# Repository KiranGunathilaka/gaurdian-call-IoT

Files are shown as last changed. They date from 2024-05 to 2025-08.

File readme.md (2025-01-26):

# GuardianCall : Multipurposed elctronic pager IoT device

GuardianCall, is a electronic pager that is developed for the ease of caretakers and bed-ridden inidividuals. This device is intended for both single patient - single caretaker and many patients - many caretakers situations.

## Market pitch

Designed by [Venumi Gihansa Gunasekara](https://github.com/venumigihansa)
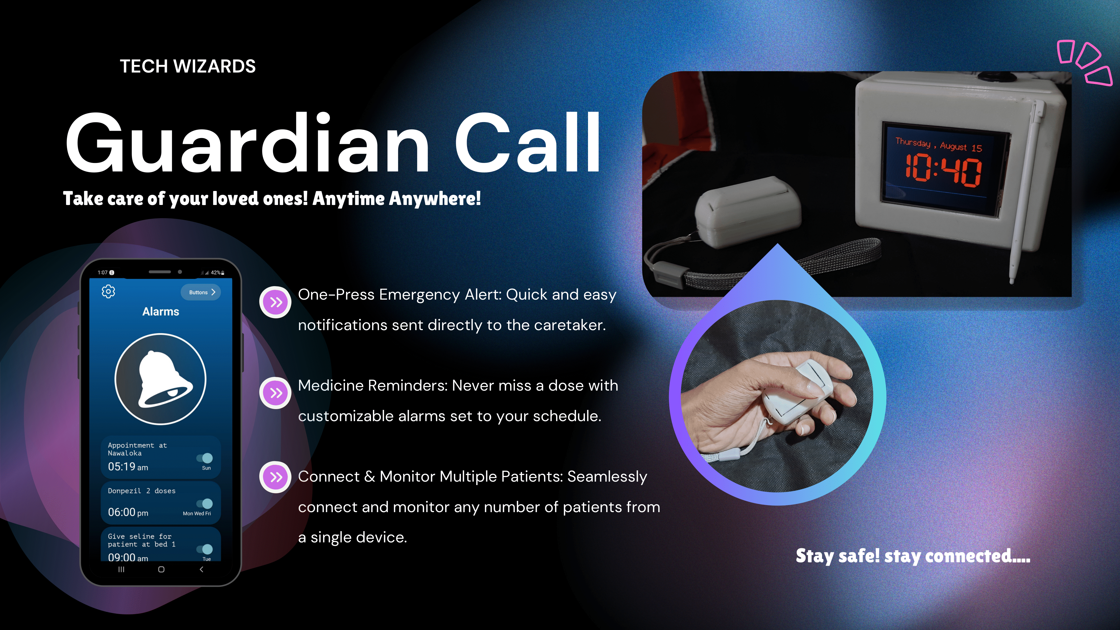
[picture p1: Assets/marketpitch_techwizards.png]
Market Pitch


## System Block Diagram

There was a major bug in the ESP32 libraries (even remaining unresolved for years in the forums), not operating WiFi and ESP Now at the same time even when the wifi channels are configured. There was no errors or execeptions throwed so we had to try different appoaches.
So after 3 system desgin iterations and considering their pros and cons we implemented our device using the following architecture.

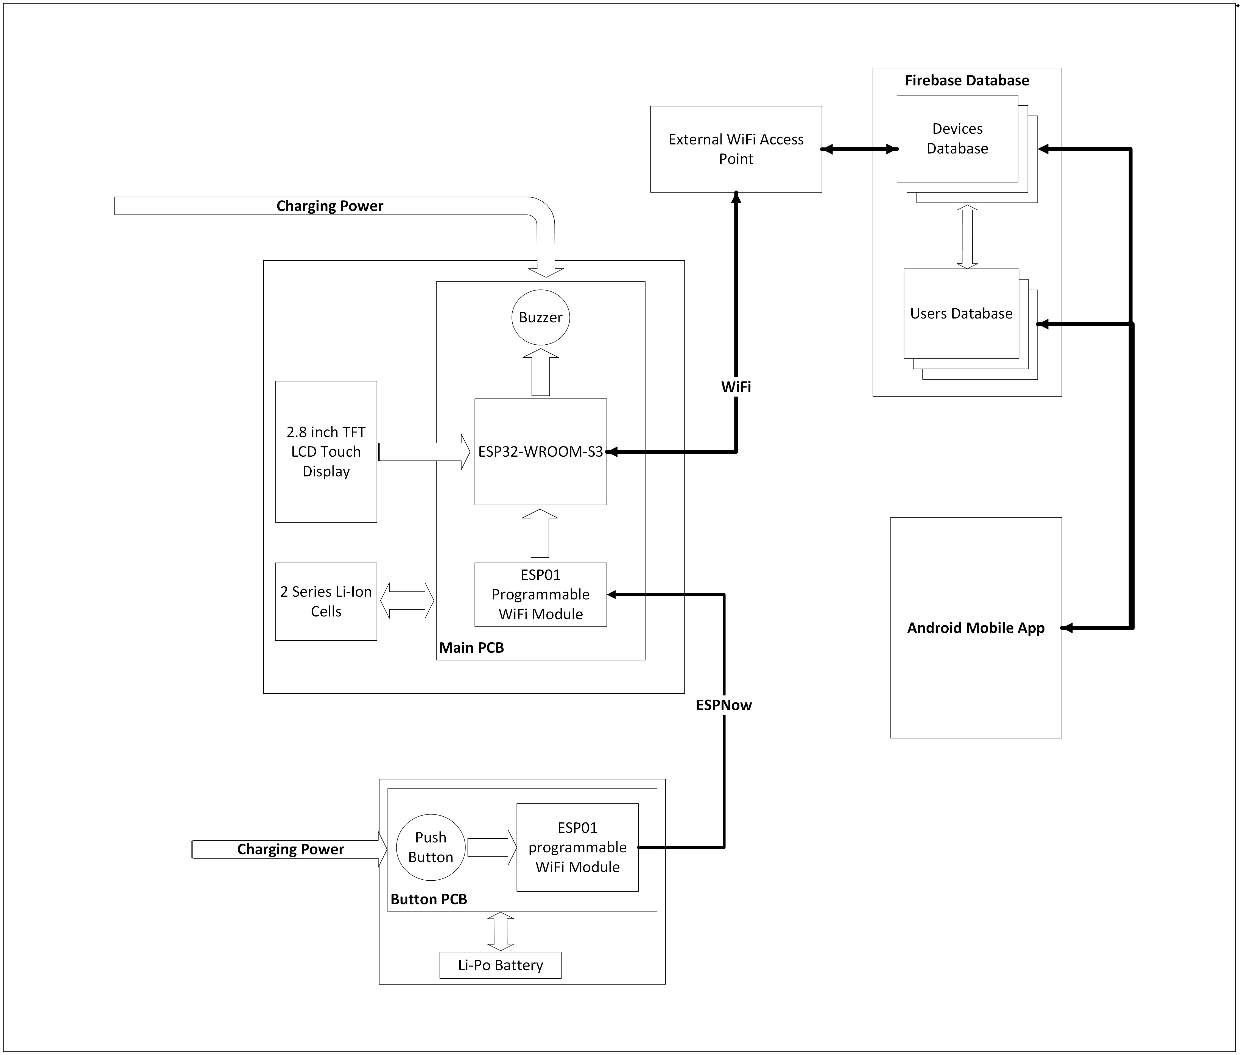
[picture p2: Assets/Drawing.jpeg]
Block diagram


## PCB Design

### Main Unit

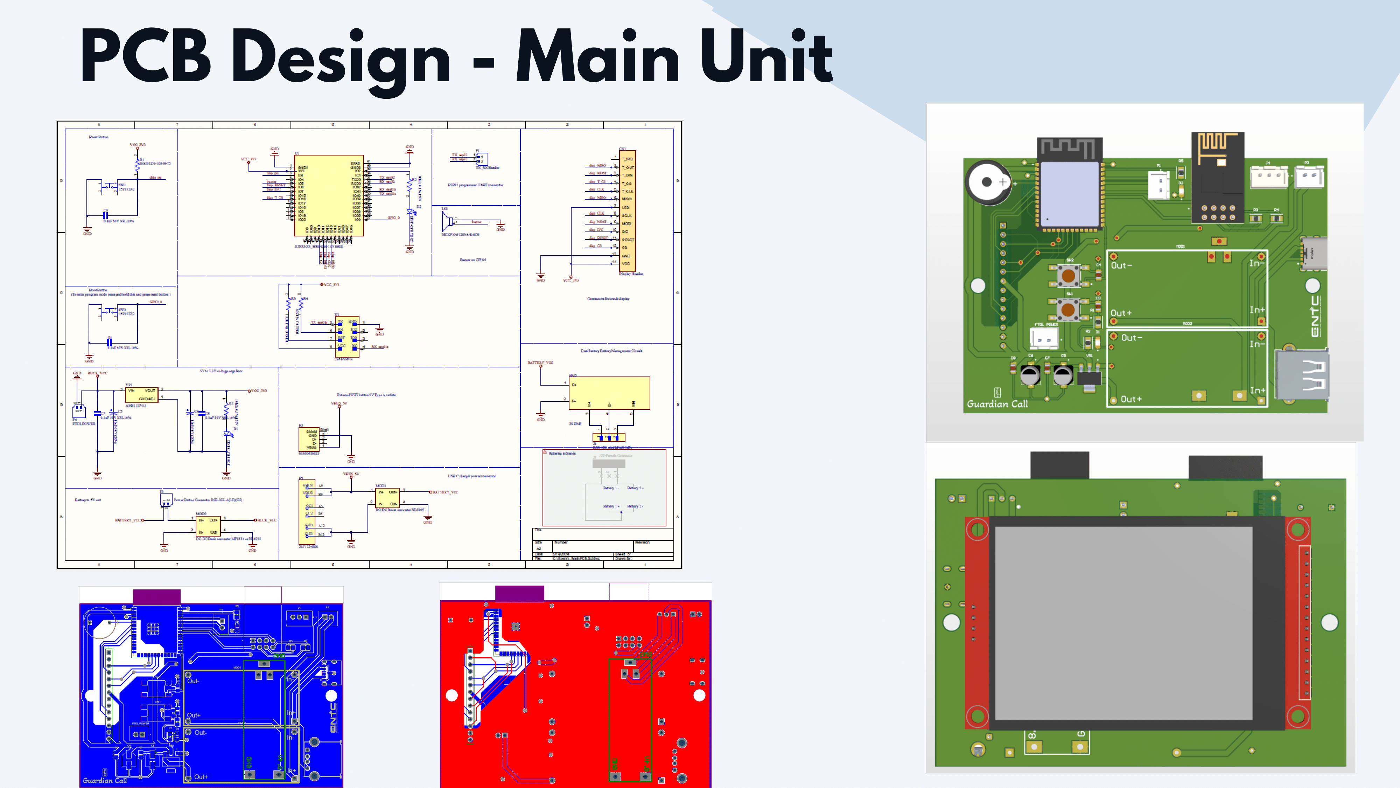
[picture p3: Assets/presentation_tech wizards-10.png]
Main PCB


### Button

Desgined by [Imansha Manuka Priyanjana](https://github.com/imansha321?tab=followers)
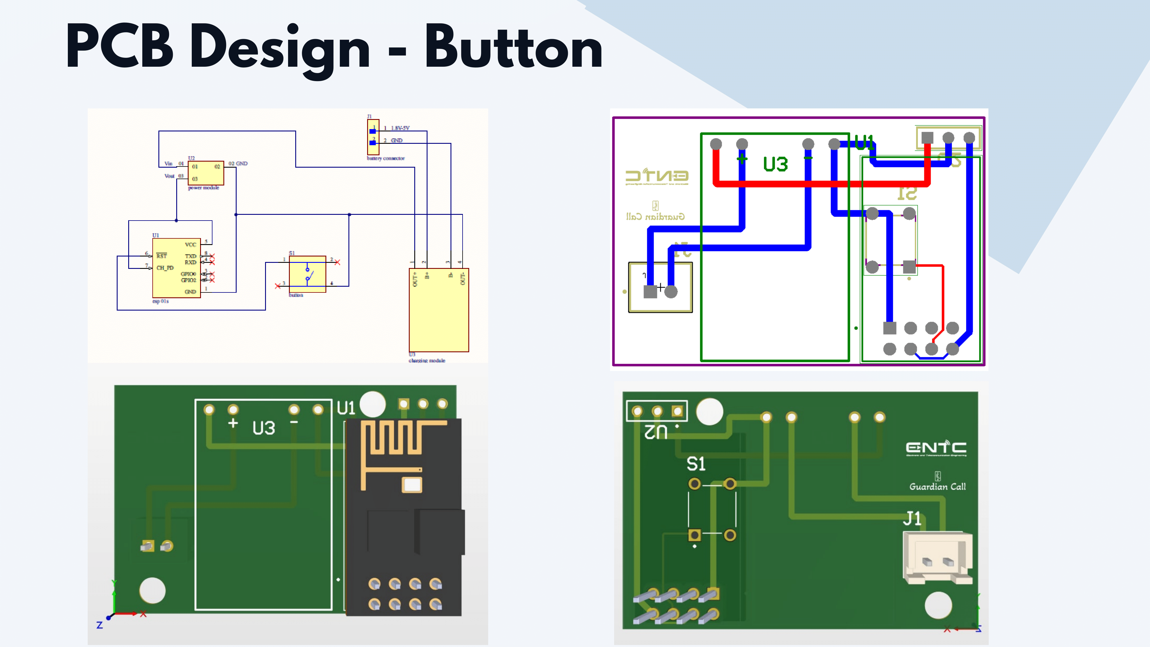
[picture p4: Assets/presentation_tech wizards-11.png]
Button PCB


<div style="display: flex; justify-content: space-around; text-align: center;">
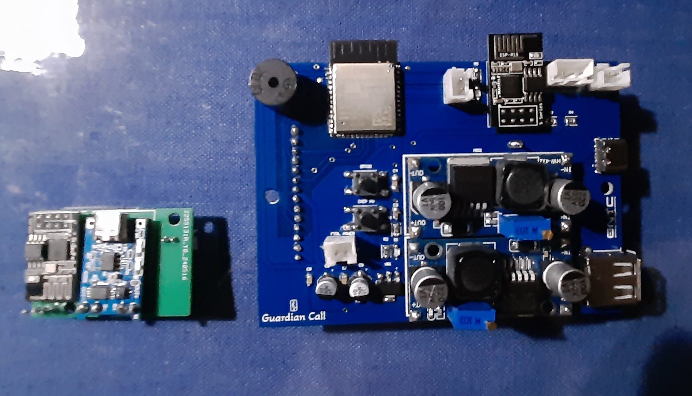
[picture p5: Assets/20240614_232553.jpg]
    
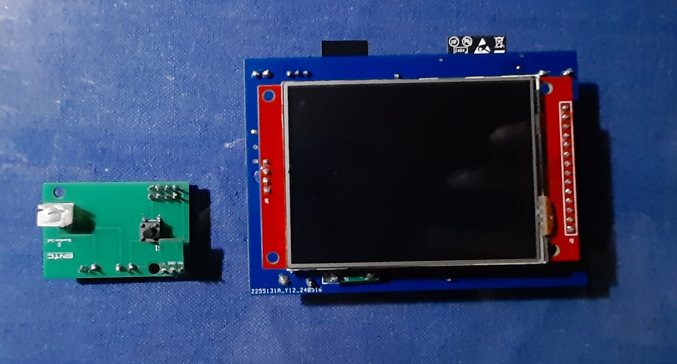
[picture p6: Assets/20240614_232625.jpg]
    
</div>

## Enclosure Design

Designed by [Induwara Illukumbura](https://github.com/induwara-iluk)
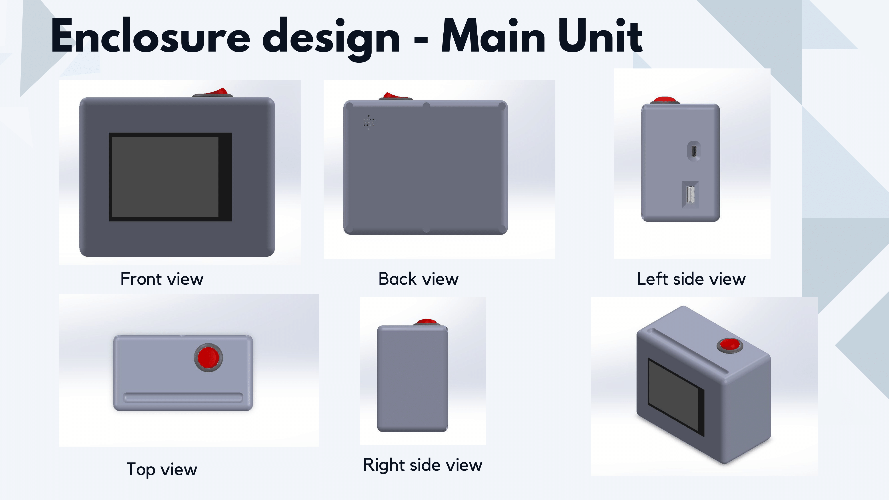
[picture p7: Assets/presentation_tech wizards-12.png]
Main unit enclosure

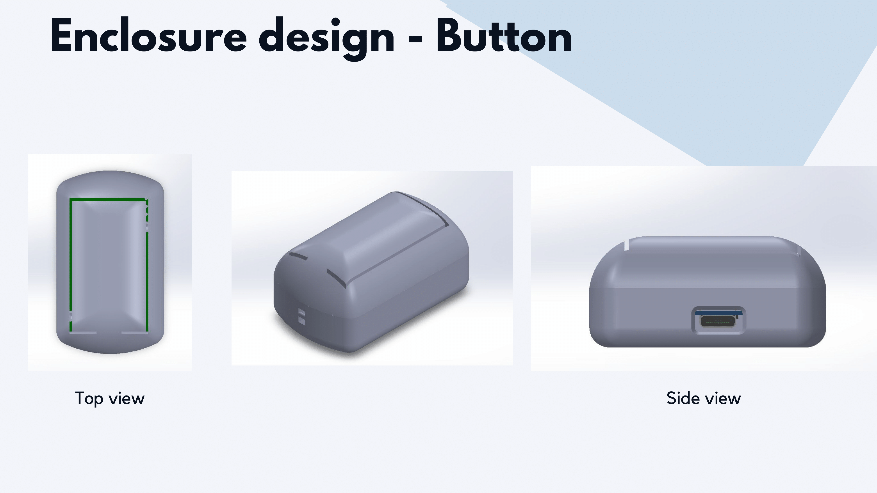
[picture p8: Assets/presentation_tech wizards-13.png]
Button enclosure


# UI of Guardian call
The existing UI is built with the TFT_eSPI library and furthur improvements will be made using LVGL.

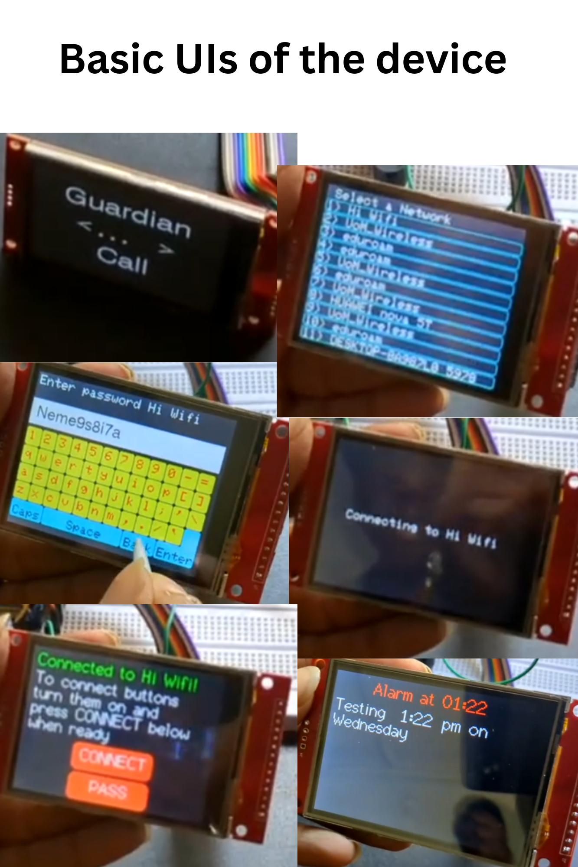
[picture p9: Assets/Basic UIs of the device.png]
UIs


## App overview

App was designed scalability and giving best user experience in mind. 

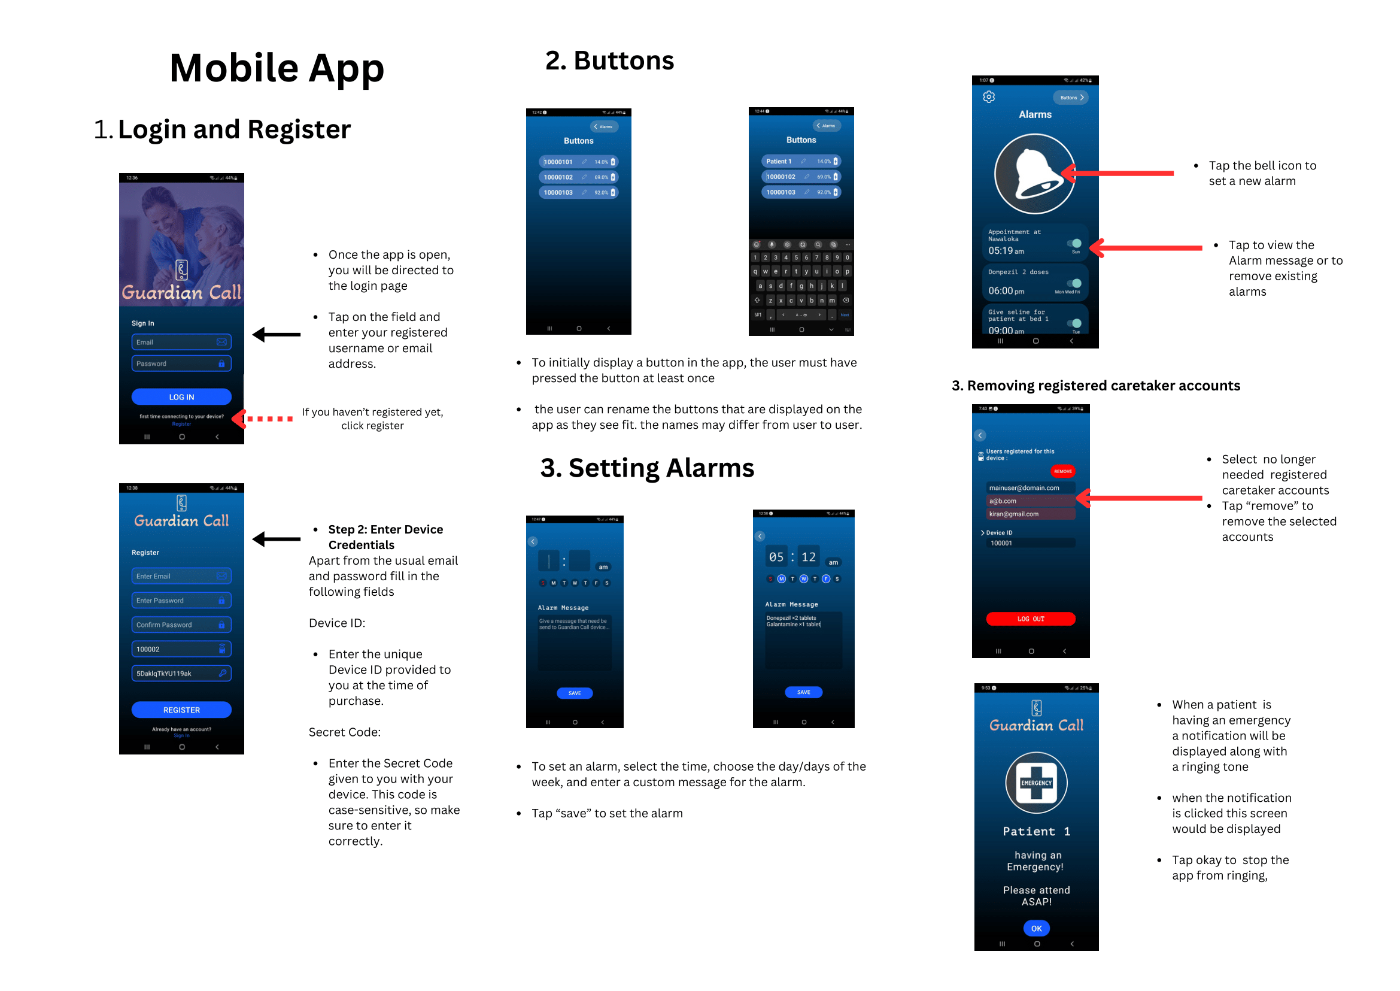
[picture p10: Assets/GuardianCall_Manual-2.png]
UI of the android app

Image credit [Venumi Gihansa Gunasekara](https://github.com/venumigihansa)

For the backend we used firebase and it's BaaS tools and the realtime database was also structured for scalabiluty making overall system architecture cabale of adding any number of new devices, users and any number of buttons for each device (but from the IoT device's firmware it is limite to 100)

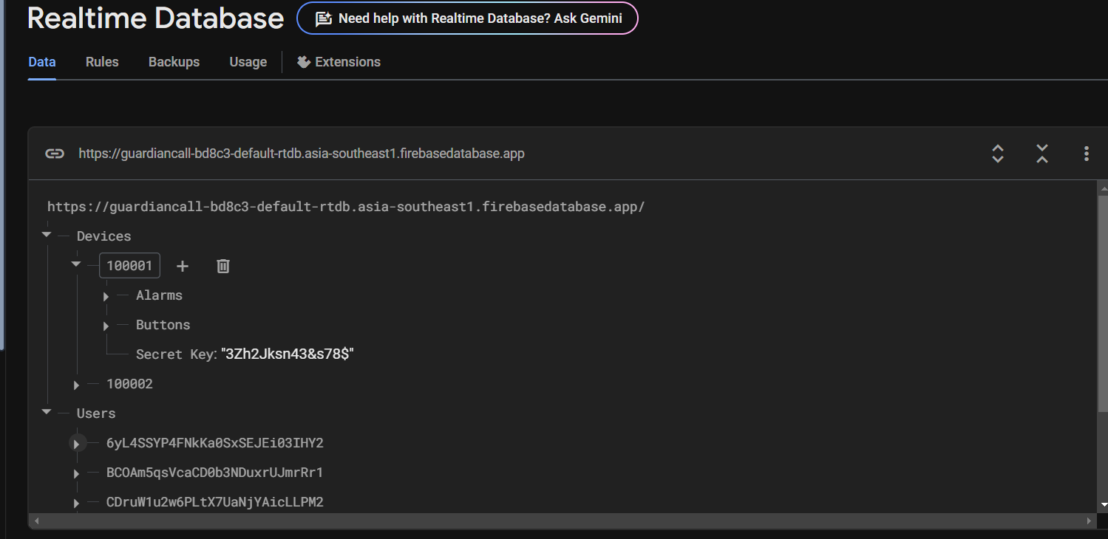
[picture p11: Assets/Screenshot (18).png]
Structure of the Realtime Database


Refer below for the source files and distributions

[Original Girhub Repo for the App](https://github.com/KiranGunathilaka/guardian-call-app)

To securely register a caretaker with a device, following sign-up cards are needed.

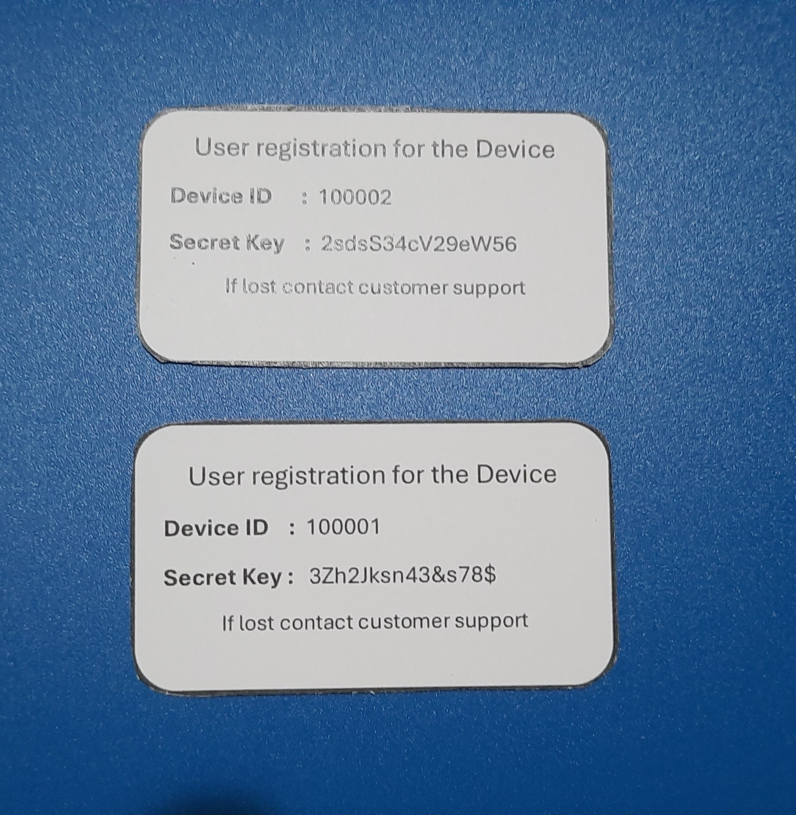
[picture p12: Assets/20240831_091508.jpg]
Sign-Up Card


## Actual Device

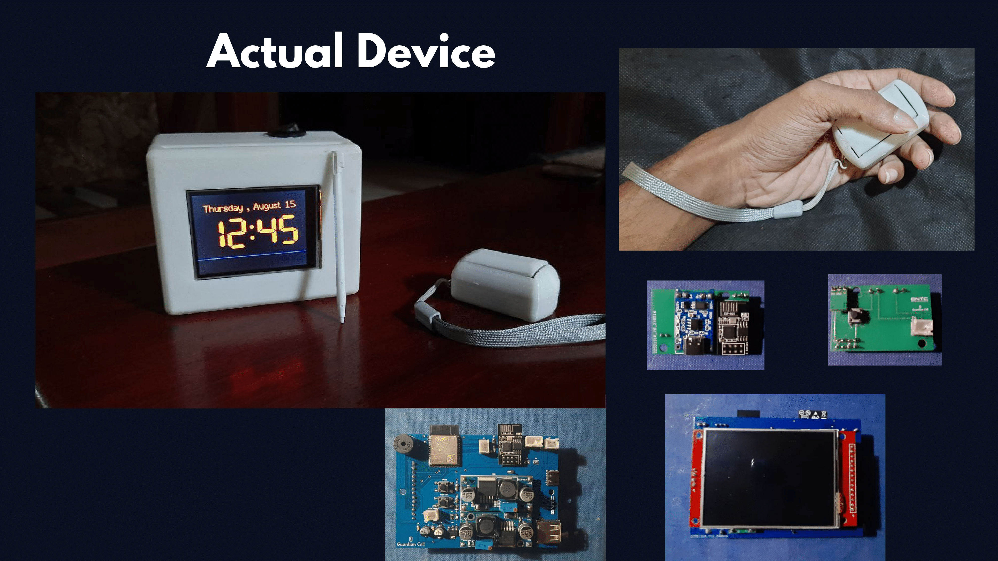
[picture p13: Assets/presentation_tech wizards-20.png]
Image of the device and pcbs


## Some videos in the prototyping phase

[Video 1, before the final circuit implmentation](Assets/VID-20240509-WA0002.mp4)

[Video 2, before using ESP01 for the button, for the proposal evalution](/Assets/VID-20240501-WA0005.mp4)

Furthur updates to the main unit is possible via a USB to TTL converter, so it is possible to make furthur improvements to the hardware after assembling.

For more information, refer to the project report, presentation pdfs above.

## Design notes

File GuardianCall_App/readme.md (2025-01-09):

# GuardianCall App

## Introduction 
Guardian call app is the mobile user interface for the GuardianCall electronic pager IoT device. Developed using android studio and java it is used for the caretakers/owners to login, register for the device, receive alert calls from the patients/Button wearers, Set alarms for the IoT device or/and app, receive alrams from the device and manage users.

## Design Overview

<div style="display: flex; justify-content: space-around; text-align: center;">
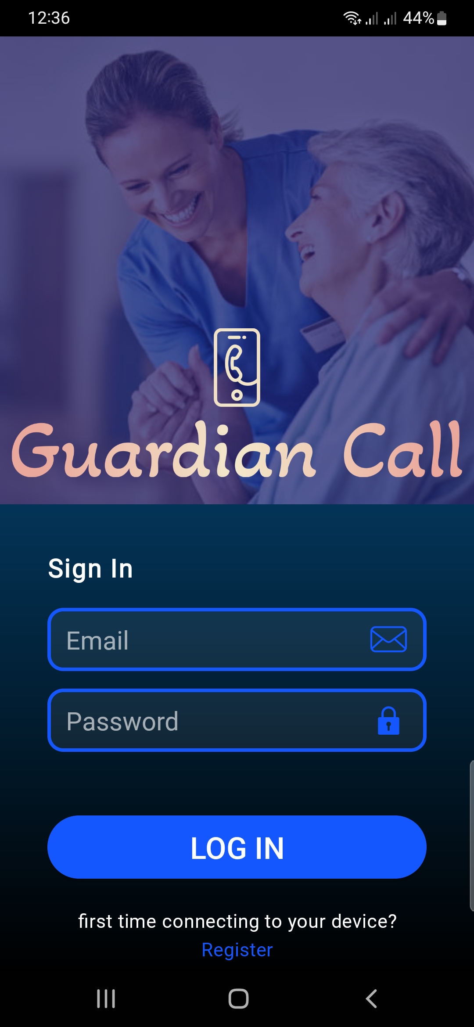
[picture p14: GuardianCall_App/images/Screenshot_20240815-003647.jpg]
  
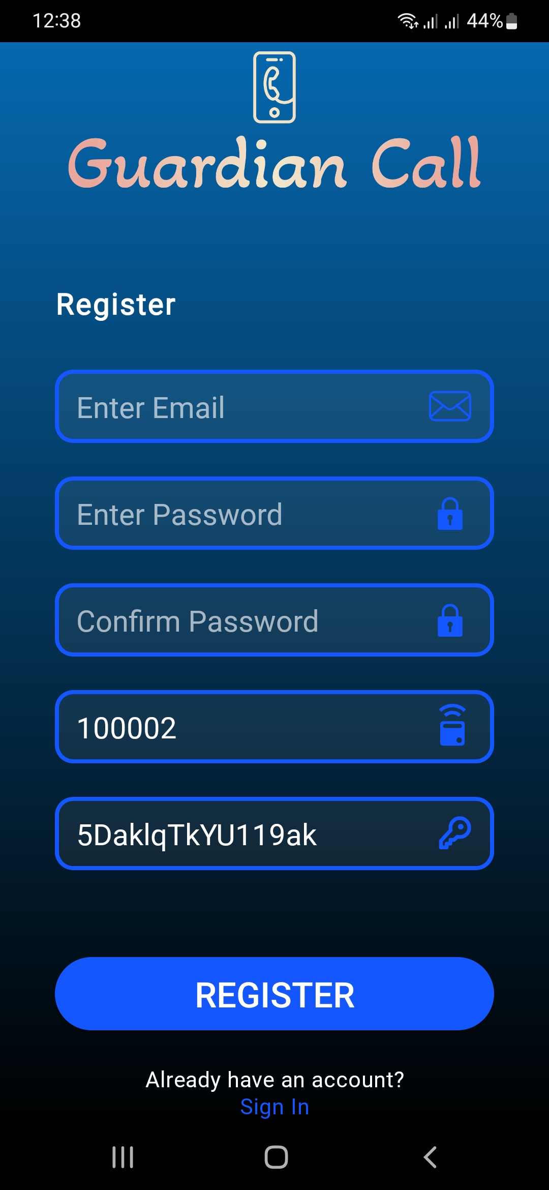
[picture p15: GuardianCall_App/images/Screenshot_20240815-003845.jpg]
  
</div>

<div style="display: flex; justify-content: space-around; text-align: center;">
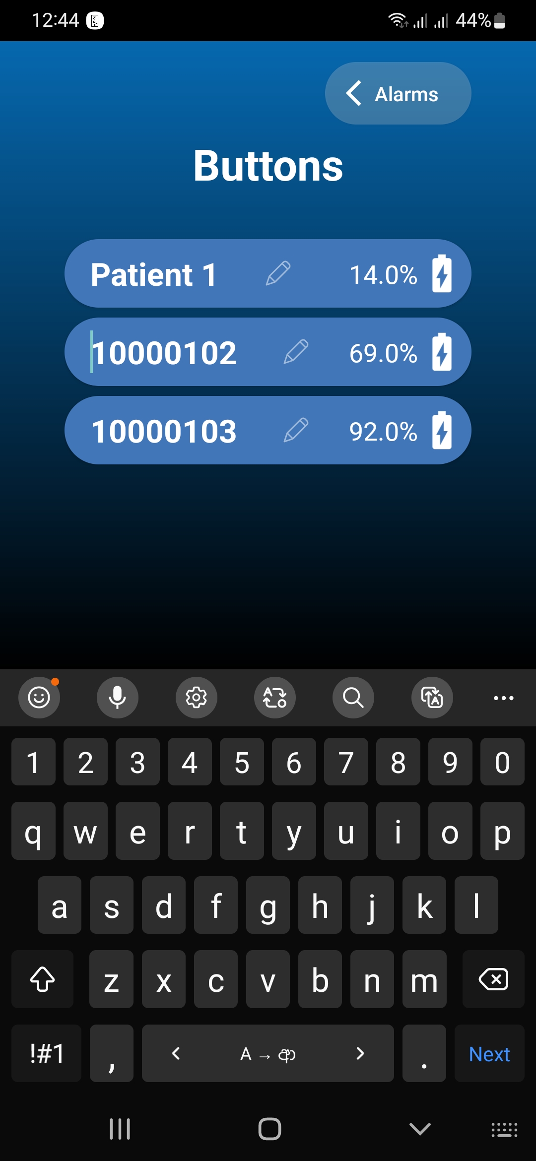
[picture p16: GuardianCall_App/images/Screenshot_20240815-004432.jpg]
    
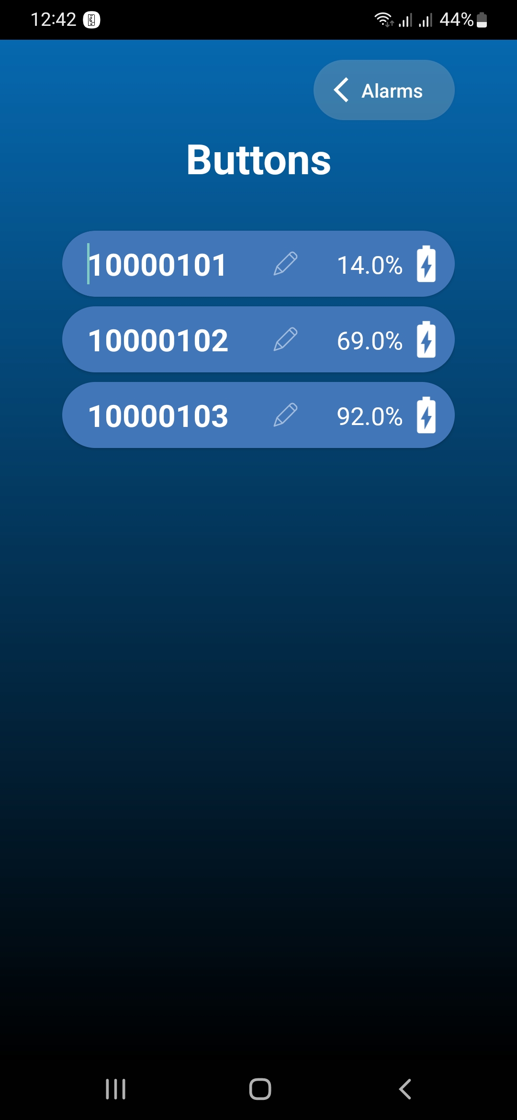
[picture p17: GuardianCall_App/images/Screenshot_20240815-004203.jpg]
    
</div>

<div style="display: flex; justify-content: space-around; text-align: center;">
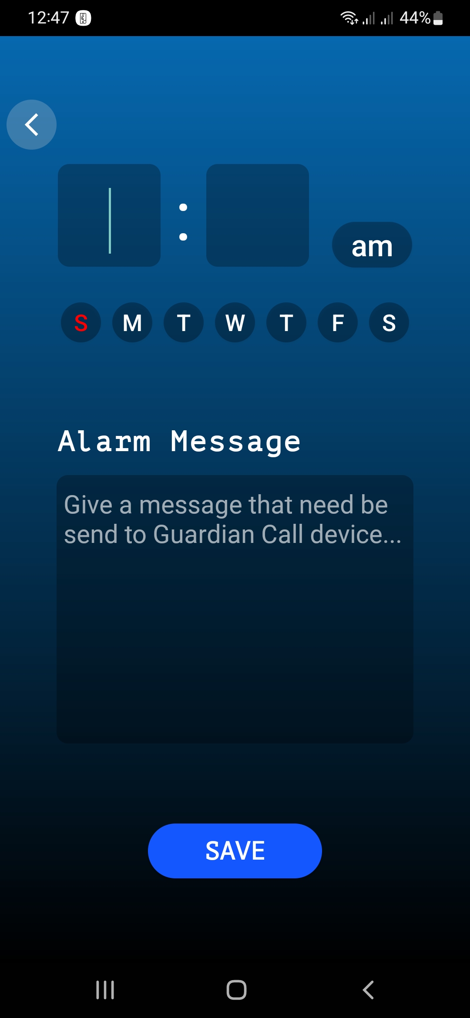
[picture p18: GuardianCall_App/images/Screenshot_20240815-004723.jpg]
    
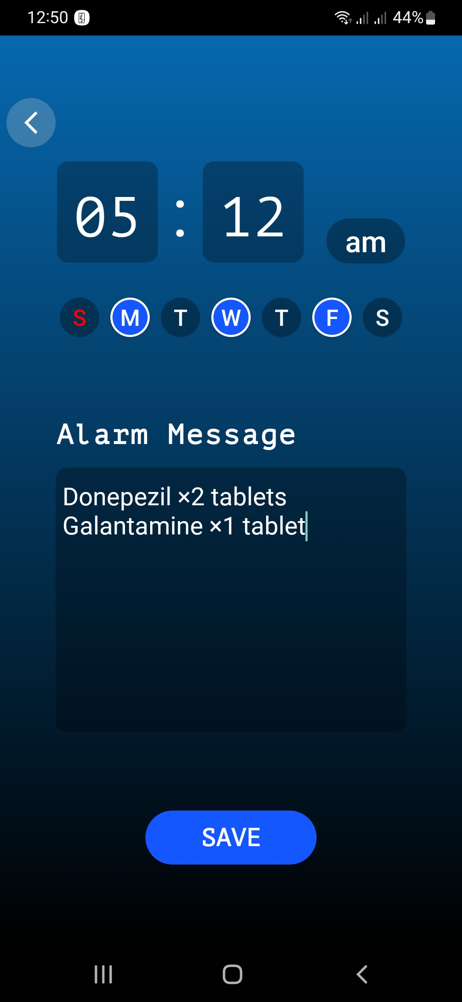
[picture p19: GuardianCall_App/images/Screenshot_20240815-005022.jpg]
    
</div>

<div style="display: flex; justify-content: space-around; text-align: center;">
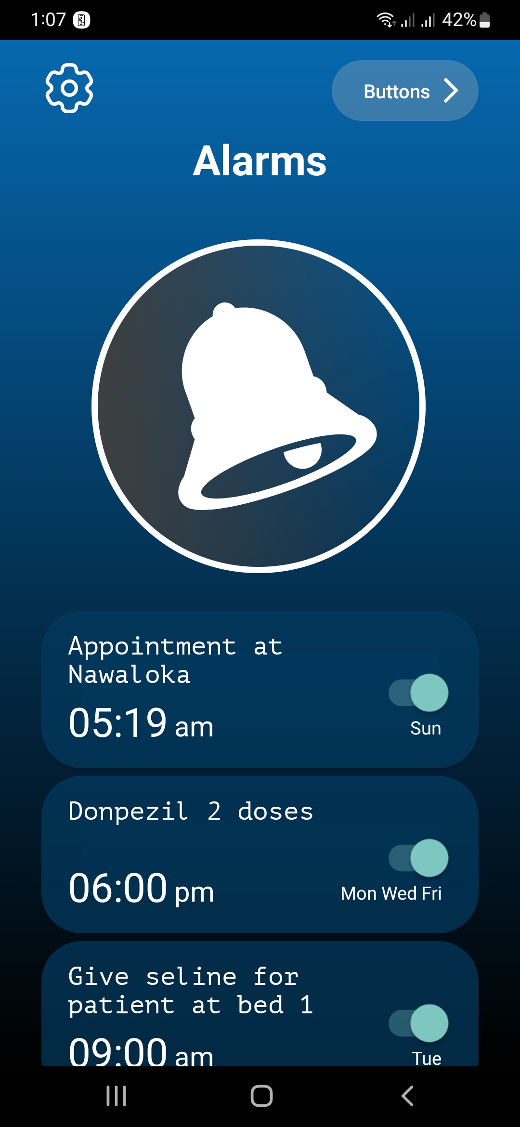
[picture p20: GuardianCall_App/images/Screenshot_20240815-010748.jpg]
    
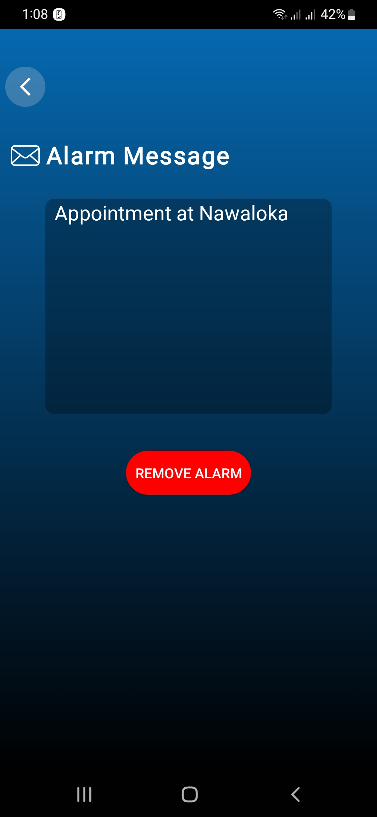
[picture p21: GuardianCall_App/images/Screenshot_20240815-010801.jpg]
    
</div>

<div style="display: flex; justify-content: space-around; text-align: center;">
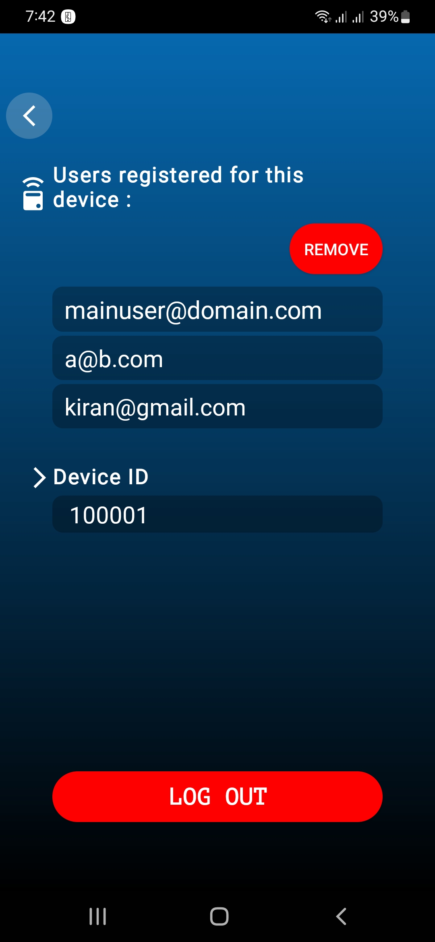
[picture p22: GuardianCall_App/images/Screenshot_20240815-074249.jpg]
    
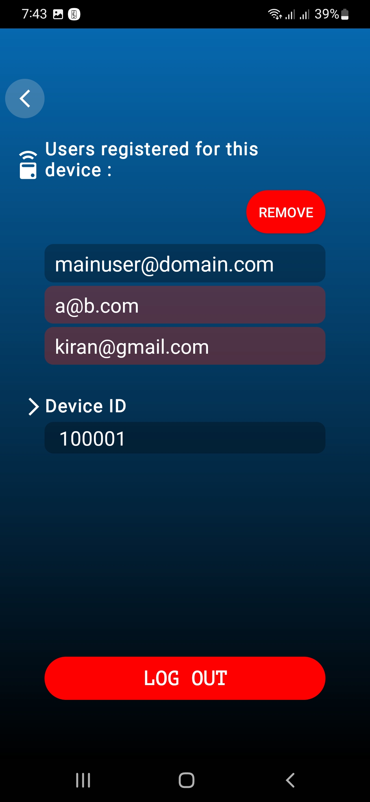
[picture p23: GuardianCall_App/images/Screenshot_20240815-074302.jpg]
    
</div>

<div style="display: flex; justify-content: space-around; text-align: center;">
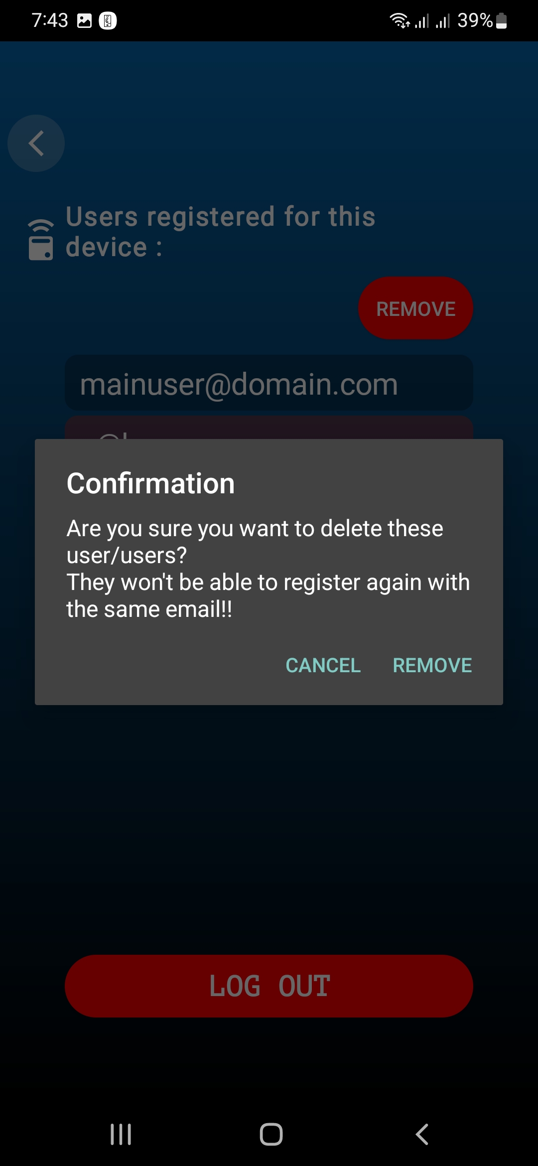
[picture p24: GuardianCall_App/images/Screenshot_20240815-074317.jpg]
    
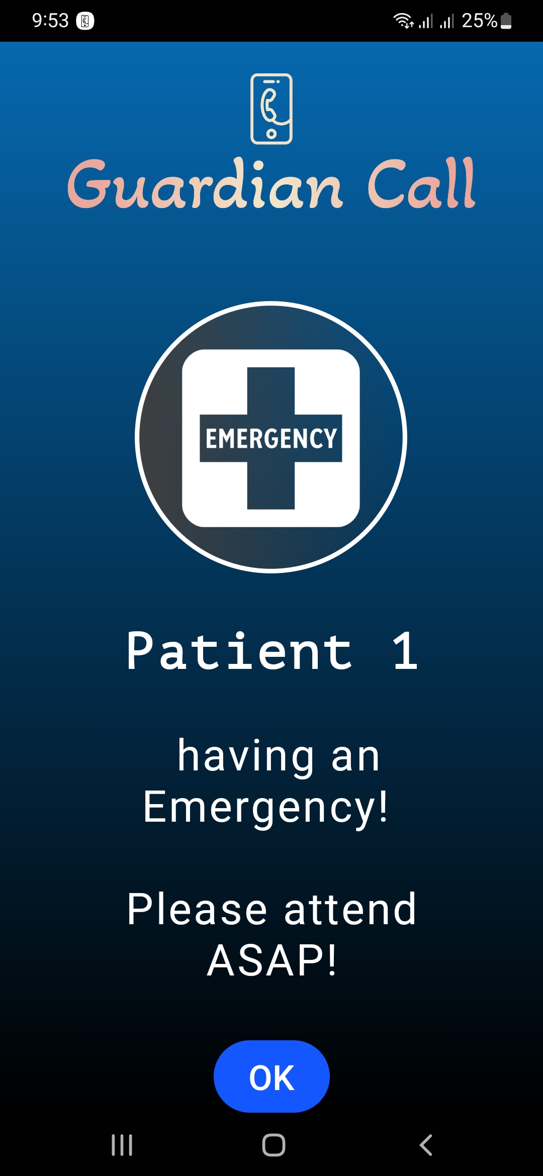
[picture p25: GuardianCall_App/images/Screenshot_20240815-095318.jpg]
    
</div>

Design Preview

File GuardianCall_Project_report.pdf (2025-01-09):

## University of Moratuwa Department of Electronic and Telecommunication Engineering EN1190 - Engineering Design Project

August 10, 2024


# Project Report on Guardian Call Group -Tech Wizards

220193M Gunasekara VGV

220197E | Gunathilaka KL
220235V | Ilukkumbura IMEIB
220495P | Priyanjana TPIM

### Contents

1 Abstract | 3
2 Introduction | 3
3 Market Research | 3
4 Product Development | 4
5 Challenges We Encountered | 5
6 Bill of Materials | 6
7 System Block Diagram | 6
8 PCB Design | 7
9 Application Development | 9
10 Enclosure Design | 10
11 Specifications | 13
12 Task Allocation | 13
13 Conclusion | 13

### 1 Abstract

GuardianCall is an adult caretaker assisting device designed to provide peace of mind to caregivers by notifying them through an app whenever assistance is required. The device also includes an alarm system to remind users about important medication schedules, ensuring comprehensive support for both the caretaker and the person in need. Key functionalities of GuardianCall include medication reminders, SOS alerts, offline alarms, and battery level indicators on the mobile app, all of which are designed to make caregiving more efficient and reliable.

### 2 Introduction

Caring for a disabled parent or loved one can be challenging, especially when you can’t leave them alone without worrying. That’s where **GuardianCall** comes in. This adult caretaker helping device ensures peace of mind by sending notifications to caretakers and relatives through our app whenever assistance is needed. Additionally, it includes an alarm system to remind the user about important medication schedules, providing comprehensive support for both the caretaker and the individual in need.

Functionalities of the GuardianCall include:
- Alarm the patient to take medicine during the given period.
- Keep records of medications taken by the patient.
- Allow the patient to send an SOS alert to the guardian via a dedicated button.
- Set alarms directly on the main device.
- Provide an offline alarm feature, ensuring alarms work even without an internet connection.
- Display a battery level indicator on mobile app.

### 3 Market Research

To validate our product concept an extensive survey was conducted and we were able to gather data from around 80 individuals through an online survey using google forms. Key focus areas of our bedside companion was identified through the survey

- Almost 54% of the respondents had an elderly or a disabled person at their households to whom they provide regular care.
- After giving a product specification,92% have responded by mentioning that having such a product would ease the tasks of the caretakers, when they are not physically present with the bedridden person.

According to the survey, this is how the respondents assumed what feature will be most beneficial to them from our product.

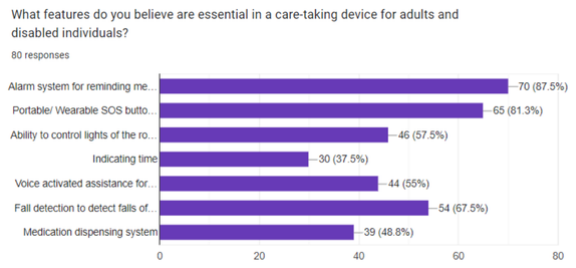
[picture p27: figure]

### 4 Product Development

### 4.1 Prototyping Attempt 01

Implementation using Arduino Uno(ATmega 328P)

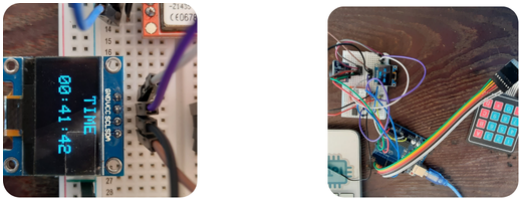
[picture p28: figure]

Why we had to shift to ESP32 from Arduino?
We initially tried to implement our design concept using arduino uno and GSM module RTC module, OLED display, keypad but we encountered network connectivity issues and memory insufficient issues.
due to that we decided to use ESP32 platform as it has inbuilt wifi capabilities, Real time clock and 520kb of SRAM to suffice our necessities and also it enabled us to introduce our product as a IoT device.

### 4.2 Prototyping Attempt 02

Implementation using ESP32(ESP32-WROOM-S3)

AS the ESP32 SoC has inbuilt wifi capabilities, real time clock, and it supports ESPNow protocol to communicate between nearby ESP devices we chose to employ an ESP01 module for the wearable button

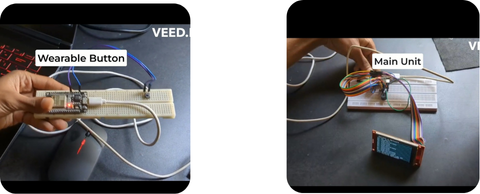
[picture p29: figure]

Prototyping Button

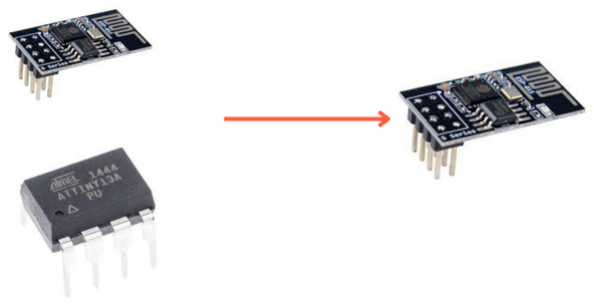
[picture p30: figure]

Initially we planned to use a ATtiny 13a in combination with ESP01 as the ATtin13a works under about 50 µA in it’s deep sleep mode, so that the ATtiny13a can turn off and on the button extending the battery life of the wearable button. But as per our testing and calculations, we found out that even without the ATtiny 13a, the deep sleep mode of the ESP01s consumes about 300µA elliminating the need of ATTiny13a to be used in our dessign.

### 5 Challenges We Encountered

1. ESPNow not working while connected to the external WiFi access point.
Solution: Employing another ESP01 in the main unit, solely for communicating with the peer ESP01 of the buttons and using serial communication between ESP32 and the mentioned ESP01 to get the button press event data.
2. Due to lack of equipment and labs being closed, using locally available soldering accessories introduced difficulties in soldering SMD components (mainly the ESP32 SoC with QFN package).
Solution: Purchasing a high-quality soldering iron with suitable tip-bits to solder SMD components.
3. Most of the SMD components that were used in our design were not available from local suppliers.
Solution: To meet previously agreed timelines, we had to import all the SMD components from online marketplaces soon after the PCB design process was over.

### 6 Bill of Materials

Component | Quantity | Price (LKR)
Buzzer | 1 | 50
2.8 TFT LCD Display | 1 | 3300
ESP 01s | 2 | 390
Step-Up Boost Convertor Module | 1 | 350
BMS | 1 | 485
Buck Convertor Module | 1 | 160
Type-C USB Socket | 1 | 75
Li-Po battery 150mAh | 1 | 480
ESP32-S3-WROOM | 1 | 1600
Boost & Buck 3.3V regulator module | 1 | 80
Li-Po Charger Module | 1 | 70
18650 Battery Case | 1 | 60
18650 Li-Ion battery | 2 | 380
Enclosure 3D Print | 1 | 3500
PCBs + Tax | 1 | 1000
Other Components | 1 | 340
Total | | 13090

Table 1: Component List and Prices

### 7 System Block Diagram

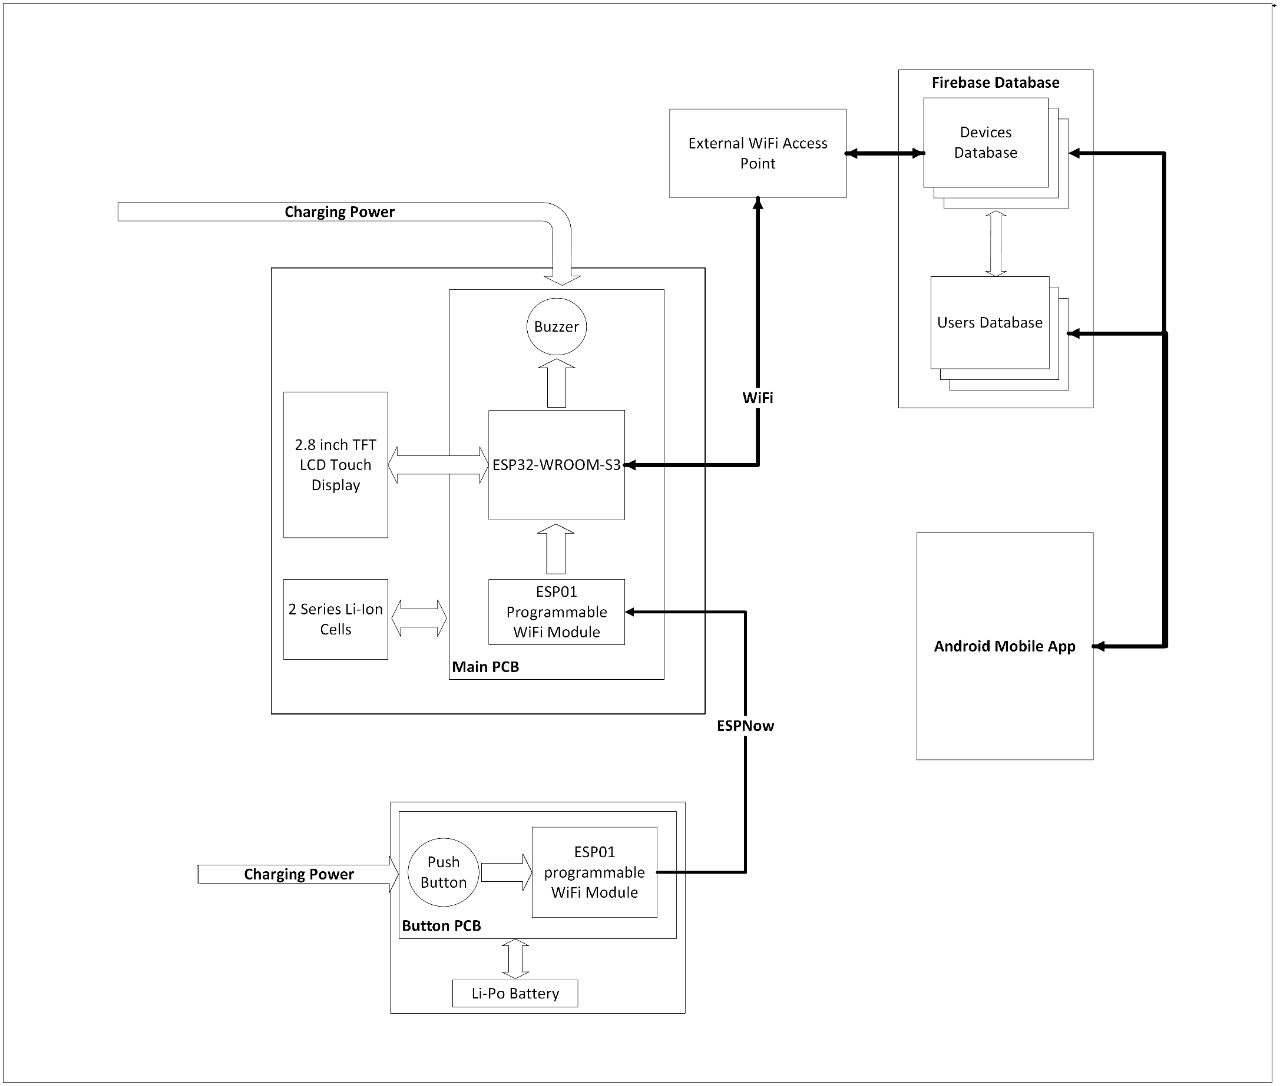
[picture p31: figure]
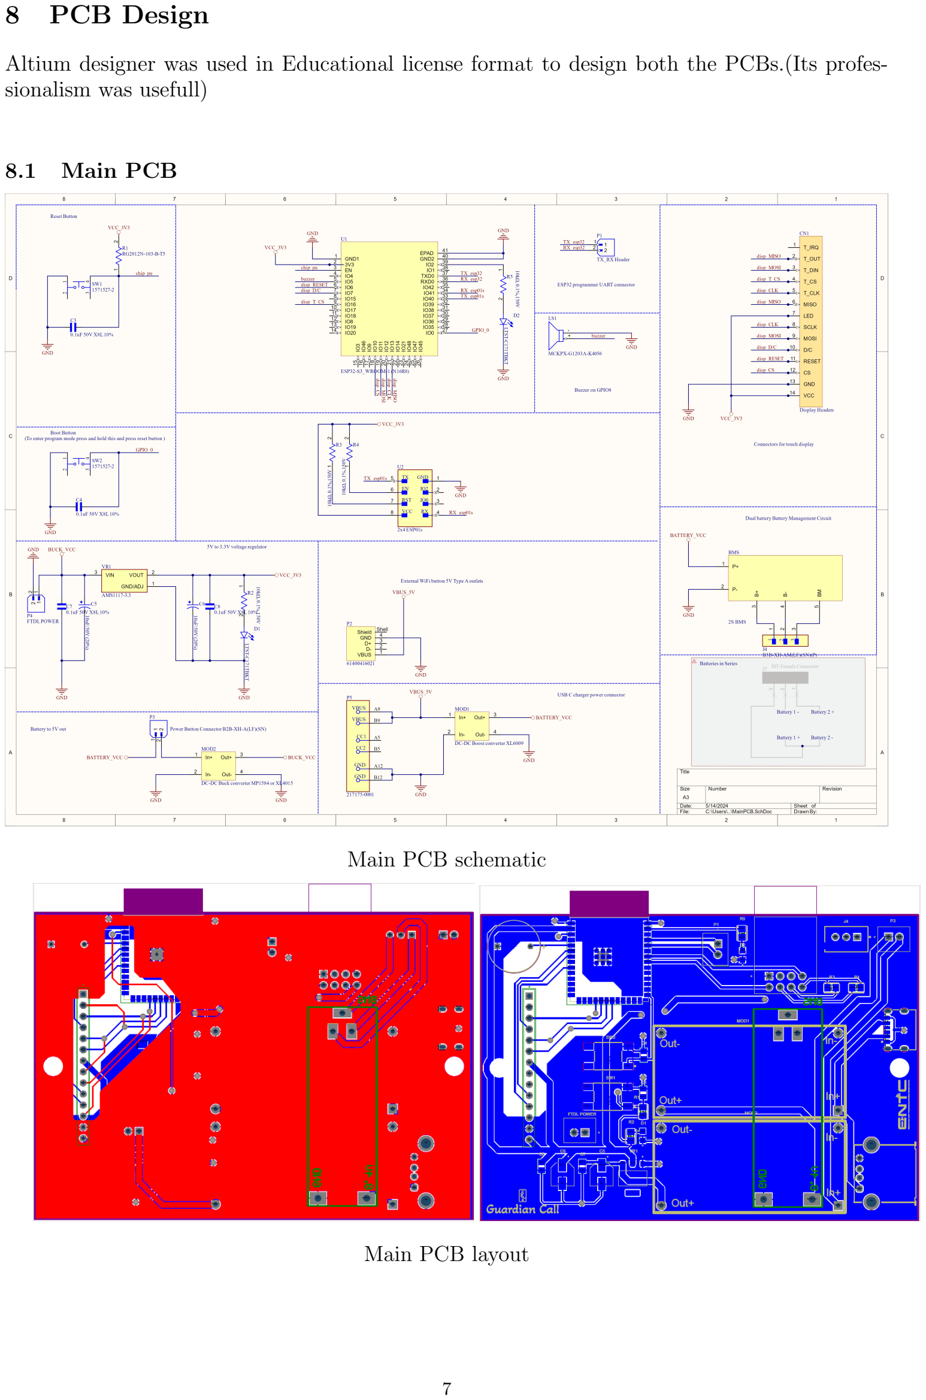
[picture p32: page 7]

### 8 PCB Design

Altium designer was used in Educational license format to design both the PCBs.(Its professionalism was usefull)

### 8.1 Main PCB

Main PCB schematic

Main PCB layout

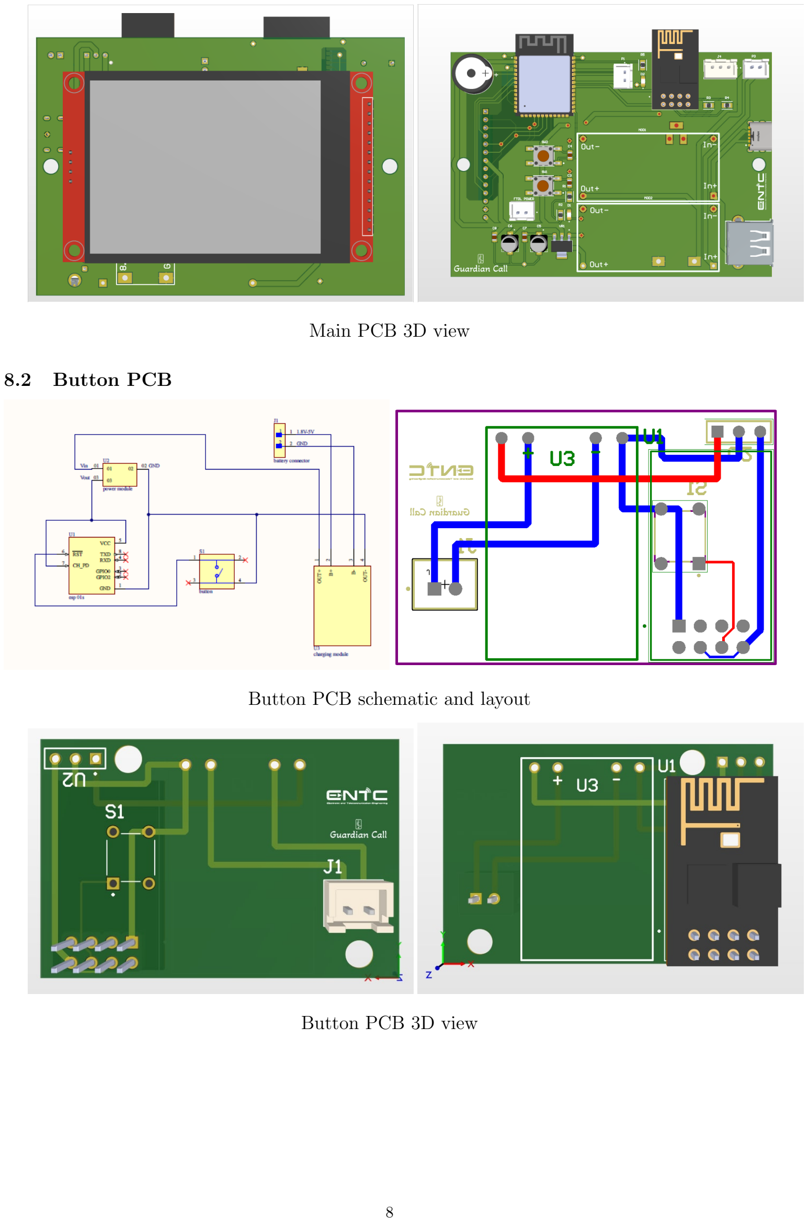
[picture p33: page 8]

Main PCB 3D view

### 8.2 Button PCB

Button PCB schematic and layout

Button PCB 3D view

### 9 Application Development

### 9.1 UI/UX Design

The initial phase of our app development involved the implementation of the UI/UX design utilizing Figma. Following this, we proceeded to develop the interface based on the finalized design.

### 9.2 Front End Development

The front-end development of the Android application was carried out using Android Studio.

### 9.3 Back End Development

Firebase served as the backend for our application, facilitating user management, and the storage of alarm details and button statuses.

### 9.4 Features

- Rings in Emergancy
- Alarm system to remind the patient to take medicine during the given period.
- Battery Level indication of button.

### 9.5 App Testing

The application was thoroughly tested on multiple devices and emulators to ensure its functionality, during which several issues were identified and resolved.

### 9.6 Mobile Interface

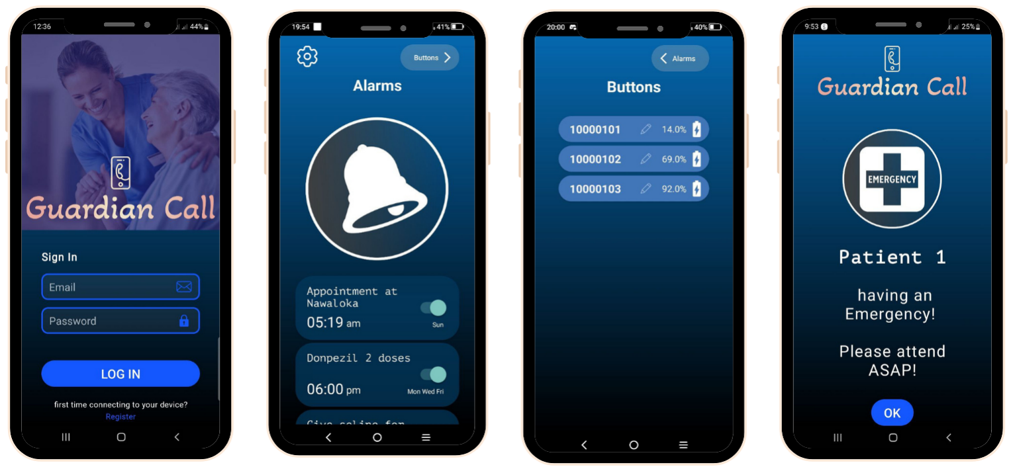
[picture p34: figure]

### 10 Enclosure Design

Solidworks 2023 Was used for Designing the 3D models of the enclosure.

### 10.1 Main Unit

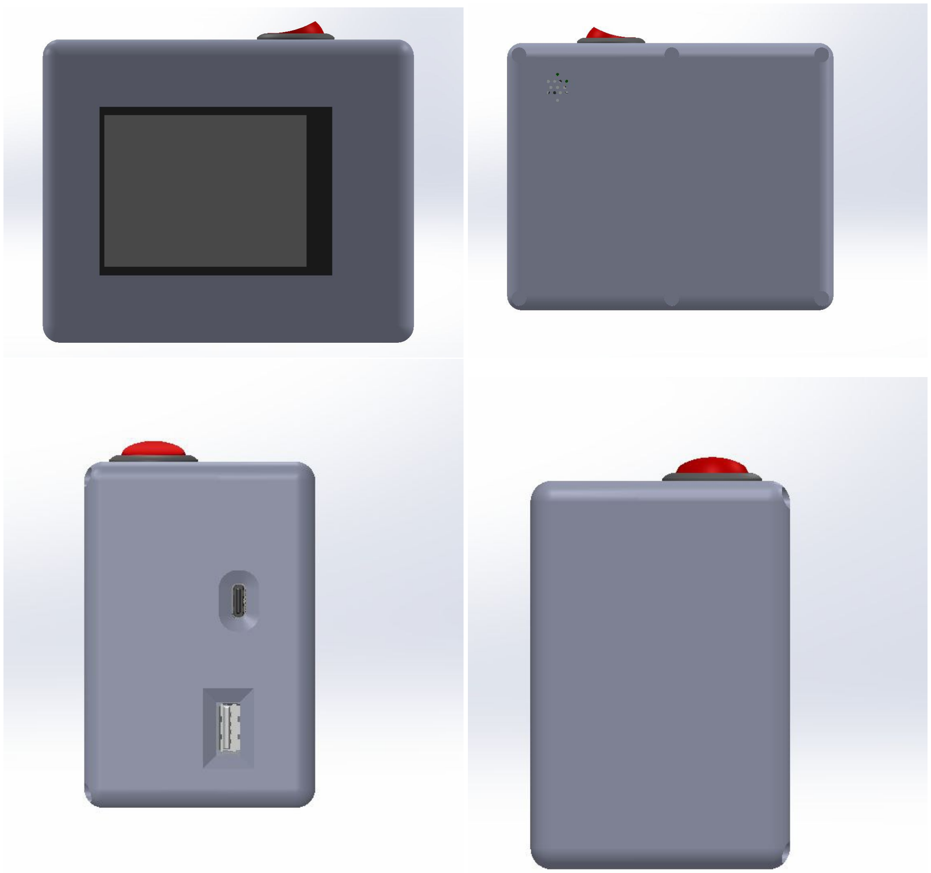
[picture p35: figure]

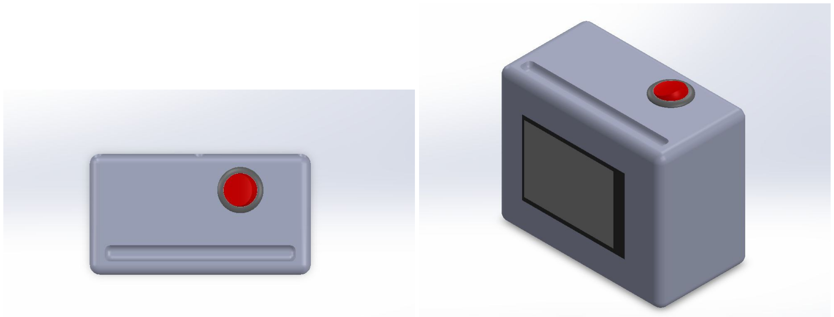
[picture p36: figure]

### 10.2 Button

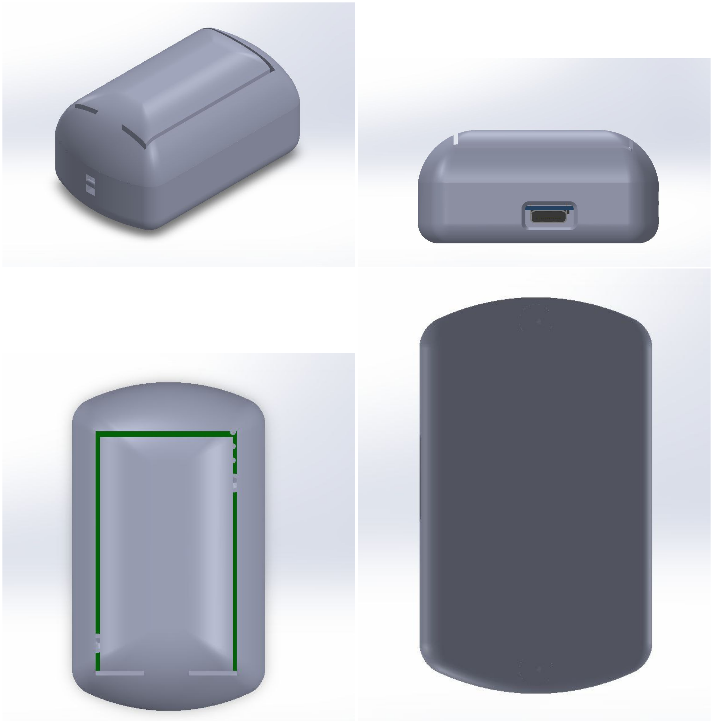
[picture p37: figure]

### 11 Specifications

Specification | Main Unit | Button
Weight | 290 g | 25 g
Height | 90 mm | 28 mm
Width | 60 mm | 35 mm
Length | 110 mm | 60 mm
Charging Time | - | 12 min
Battery Life | 18 h | 20 days
Battery Capacity | 3600 mAh | 150mAh
Operating Voltage | 8.4-6.0 V | 4.2-3.0 V
Operating Current | 200 mA | Button Press - 140.6 mA (1.1 Seconds) Deep Sleep - 300uA
Power Consumption | 1.68 W | 1.3 mW
Range | - | -

Table 2: Combined Specifications of Main Unit and Button

### 12 Task Allocation

Gunasekara VGV 220193M | Gunathilaka KL 220197E | Ilukkumbura IMEIB 220235V | Priyanjana TPIM 220495P
Research survey | PCB design of Main unit | 3D enclosure design (Main device, Button) | PCB design of the Button
App development | App development | App development | App development
Documentation | Programming micro-controller | Assembling | Programming micro-controller
Testing | Soldering | Documentation | Soldering

Table 3: Team Member Responsibilities

### 13 Conclusion

Our project began with a solid understanding of how to identify a solvable question and conduct thorough research on the Optimal Design Solution (ODS). We successfully designed our own prototypes and delved into various aspects of development, including PCB design, 3D modeling, coding, and communication technologies. Our implementations aligned well with our expectations, and we managed to meet most of our goals.
However, we encountered challenges with the charging module, which remains an area for further improvement. Despite this, our experience has highlighted potential avenues for future development. We are committed to continuing the enhancement of this product, building on the foundation we’ve established.

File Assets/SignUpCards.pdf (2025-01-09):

User registration for the Device; Device ID : 100001; Secret Key : 3Zh2Jksn43&s78$; If lost contact customer support; Device ID : 100002; Secret Key : 2sdsS34cV29eW56

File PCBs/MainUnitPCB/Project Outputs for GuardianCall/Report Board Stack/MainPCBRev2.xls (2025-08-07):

Board Stack Report
Stack Up |  | Layer Stack
Layer | Board Layer Stack | Name | Material | Thickness | Constant
1 |  | Top Overlay |  | 0mil
2 |  | Top Solder | Solder Resist | 0.394mil | 3.5
3 |  | Top Layer |  | 1.378mil
4 |  | Dielectric 1 | FR-4 | 59.055mil | 4.8
5 |  | Bottom Layer |  | 1.378mil
6 |  | Bottom Solder | Solder Resist | 0.394mil | 3.5
7 |  | Bottom Overlay |  | 0mil
 | Height : 62.599mil

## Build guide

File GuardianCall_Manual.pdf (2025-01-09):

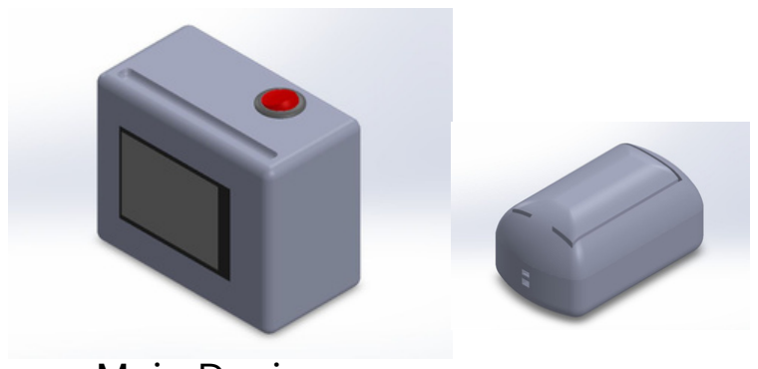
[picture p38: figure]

Main Device | SOS Button

# Guardian Call

## The GuardianCall system offers real-time notifications, medication reminders, and SOS alerts to support caretakers and relatives. It includes a main device, an SOS button, and a mobile app, ensuring your loved ones

are always connected and cared for.

## This device Has 3 main components

## Main Device SOS Button Mobile App

## Mobile App

# SOS Button

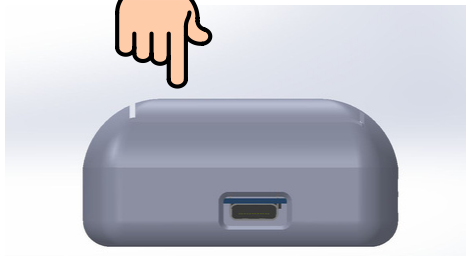
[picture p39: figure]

# Charging Port: Charges using a

standard USB-C charger.

# Pressing Button: sends an emergency alert to all the

caretaker’s smartphones.

# Strap is put around the wrist One battery Cycle last upto 20 days

# Main Device

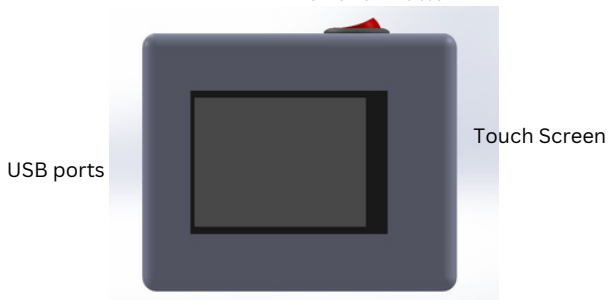
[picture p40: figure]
Touch Screen USB ports

Power on Button

For Charging main device

For charging the SOS button

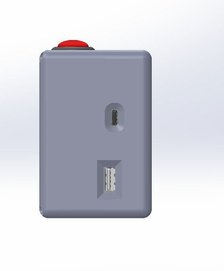
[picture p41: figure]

# 1.Initial Setup: On first boot, select a Wi-Fi network and enter the password using the provided PIN. The password won't be needed again

for the same network.

# 2.Wi-Fi Connection: The device auto-connects if the network is available. If Wi-Fi is off, a pop-up will prompt you to switch networks or retry. Pressing space registers a new Wi-Fi, which will

auto-connect once available.

# 3.No Wi-Fi Connection: The device beeps continuously if no Wi-Fi is available. Connect to

Wi-Fi to use the mobile app.

# 4.Charging: Charge the device via the USB-C port. Use the USB-A port to charge

the button.

## Pen for Easy touch

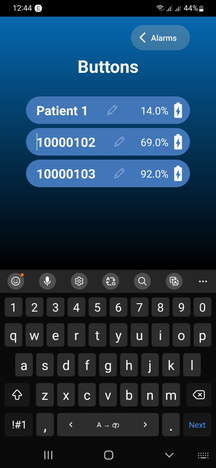
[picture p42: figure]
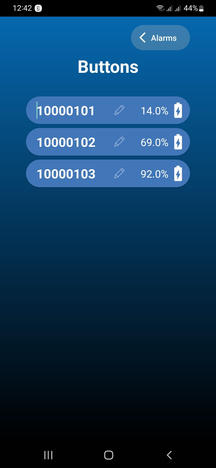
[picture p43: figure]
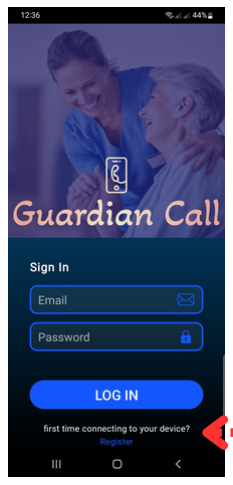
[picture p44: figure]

Once the app is open,
you will be directed to
the login page

Tap on the field and
enter your registered
username or email
address.

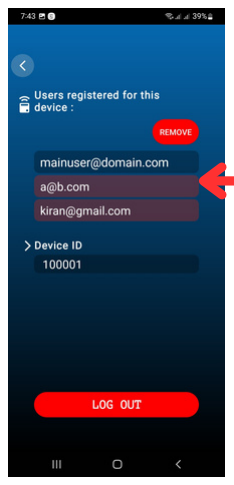
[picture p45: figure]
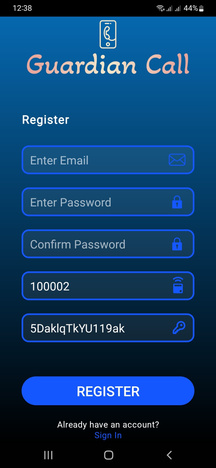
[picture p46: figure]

Step 2: Enter Device
Credentials
Apart from the usual email and password fill in the
following fields

Device ID:

Enter the unique
Device ID provided to
you at the time of
purchase.

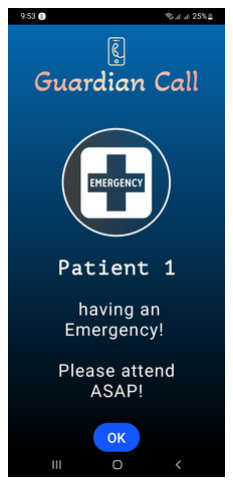
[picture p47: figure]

Secret Code:

Enter the Secret Code
given to you with your
device. This code is
case-sensitive, so make
sure to enter it
correctly.

# Mobile App

# 1.Login and Register

# 2. Buttons

# 3. Setting Alarms

To initially display a button in the app, the user must have pressed the button at least once

the user can rename the buttons that are displayed on the app as they see fit. the names may differ from user to user.

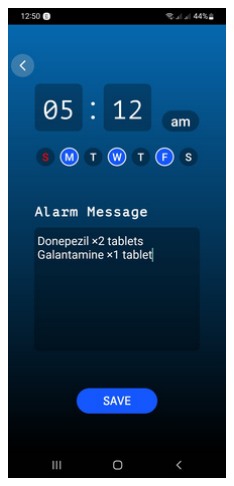
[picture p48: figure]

To set an alarm, select the time, choose the day/days of the week, and enter a custom message for the alarm.

Tap “save” to set the alarm

Tap the bell icon to
set a new alarm

Tap to view the
Alarm message or to
remove existing
alarms

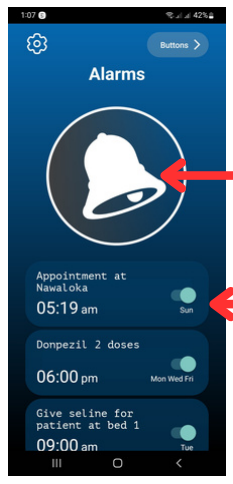
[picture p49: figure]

### 3. Removing registered caretaker accounts

Select no longer
needed registered
caretaker accounts
Tap “remove” to
remove the selected
accounts

When a patient is
having an emergency
a notification will be
displayed along with
a ringing tone

when the notification
is clicked this screen
would be displayed

Tap okay to stop the
app from ringing,

If you haven’t registered yet, click register

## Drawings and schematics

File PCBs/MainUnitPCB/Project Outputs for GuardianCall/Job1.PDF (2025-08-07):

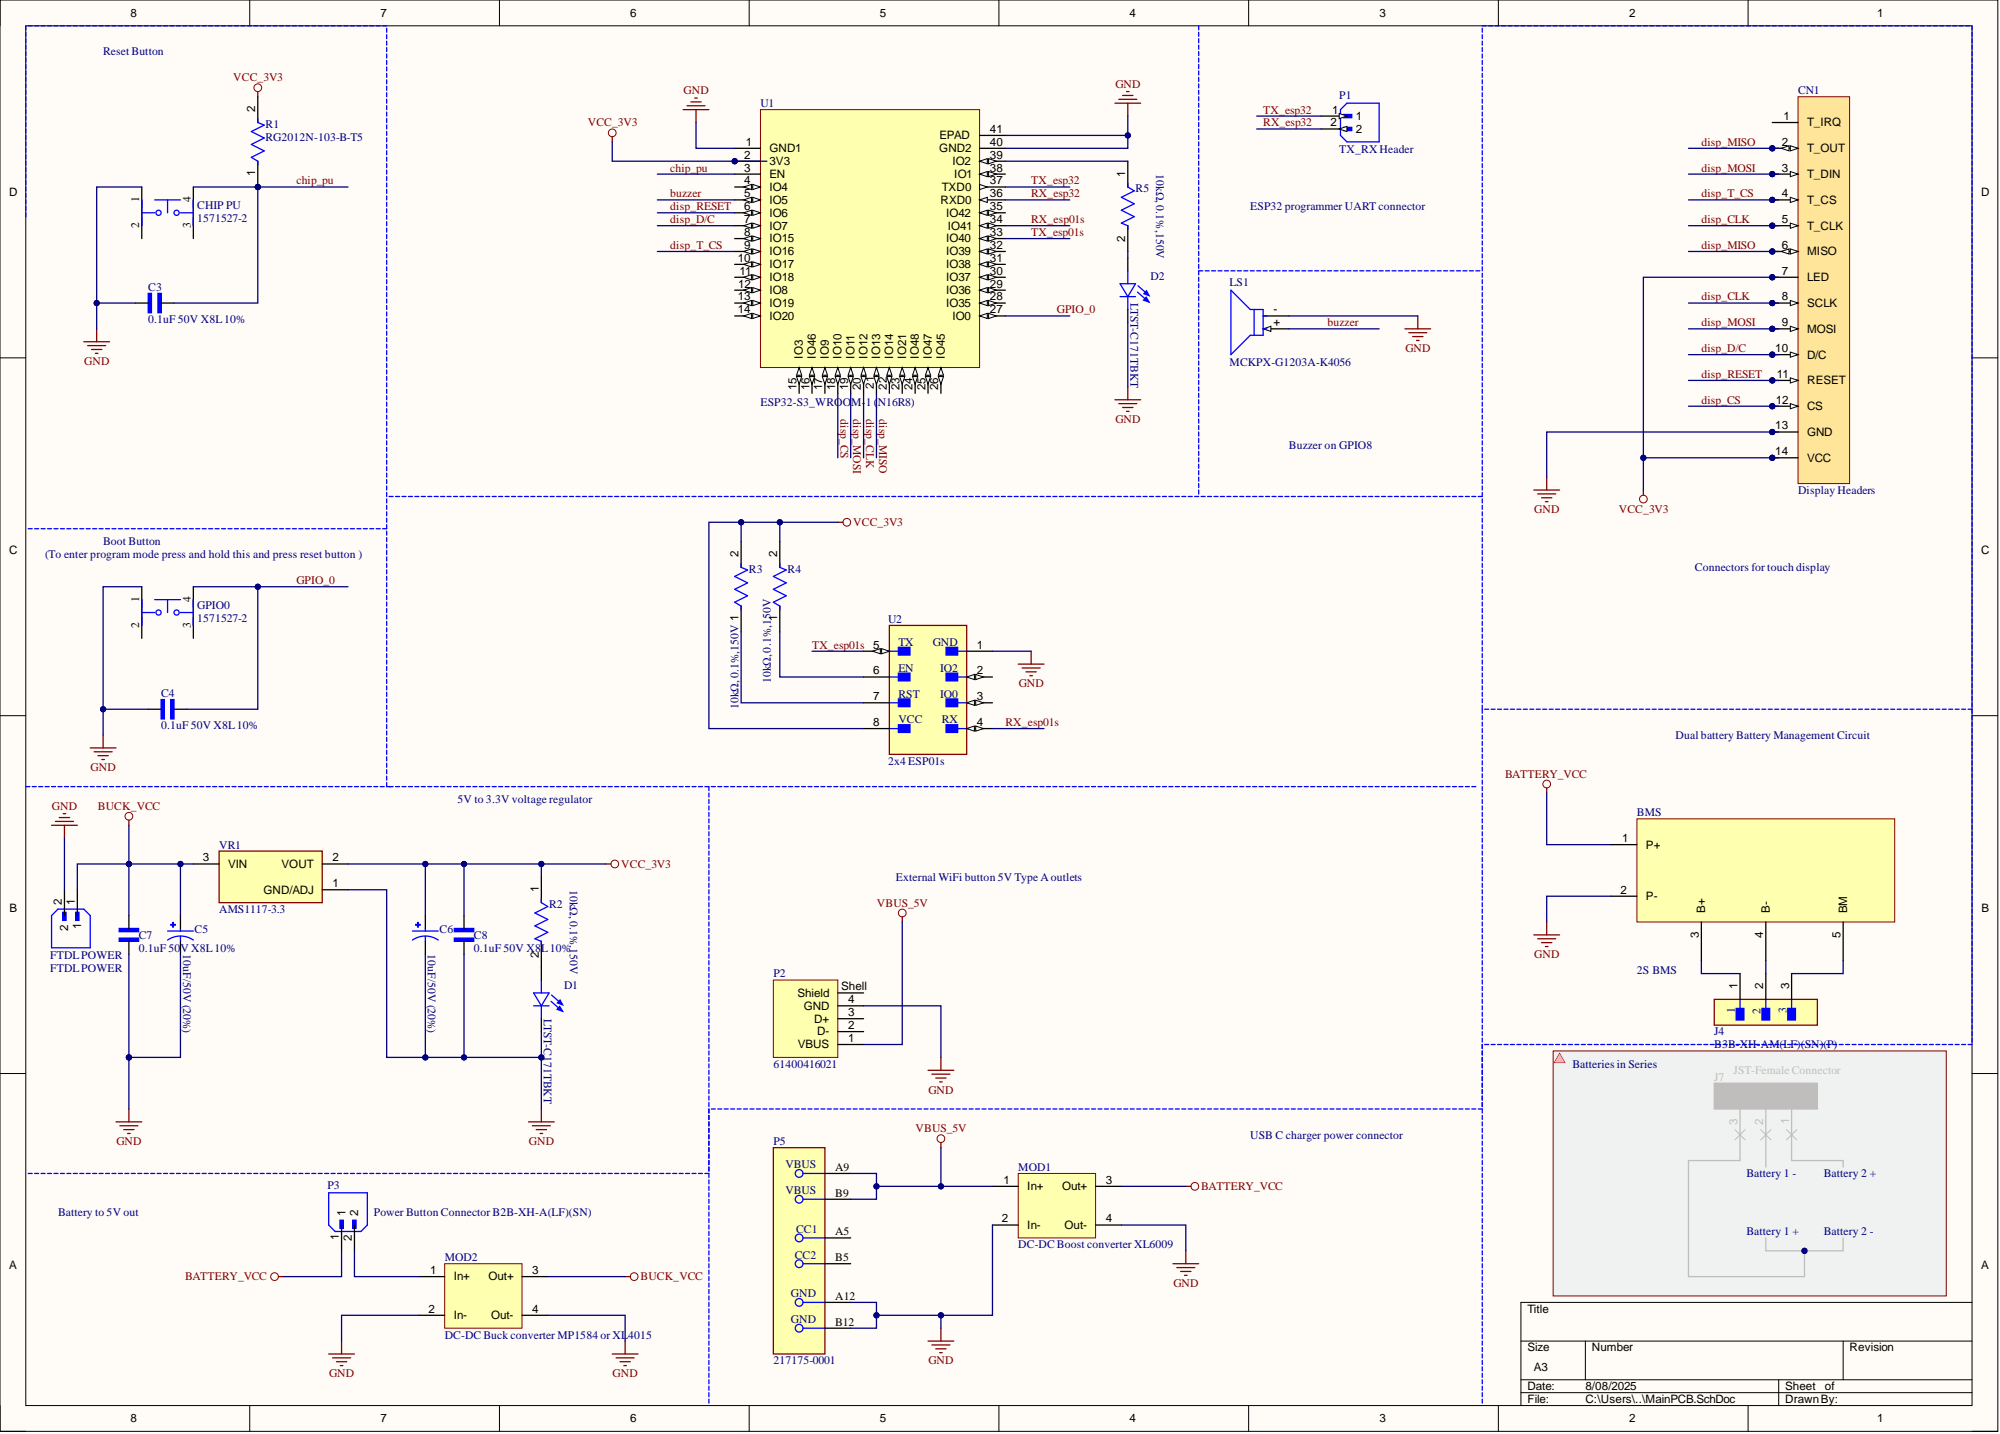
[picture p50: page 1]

(To enter program mode press and hold this and press reset button )

Connectors for touch display

Dual battery Battery Management Circuit

External WiFi button 5V Type A outlets

USB C charger power connector

Power Button Connector B2B-XH-A(LF)(SN)

DC-DC Boost converter XL6009

DC-DC Buck converter MP1584 or XL4015

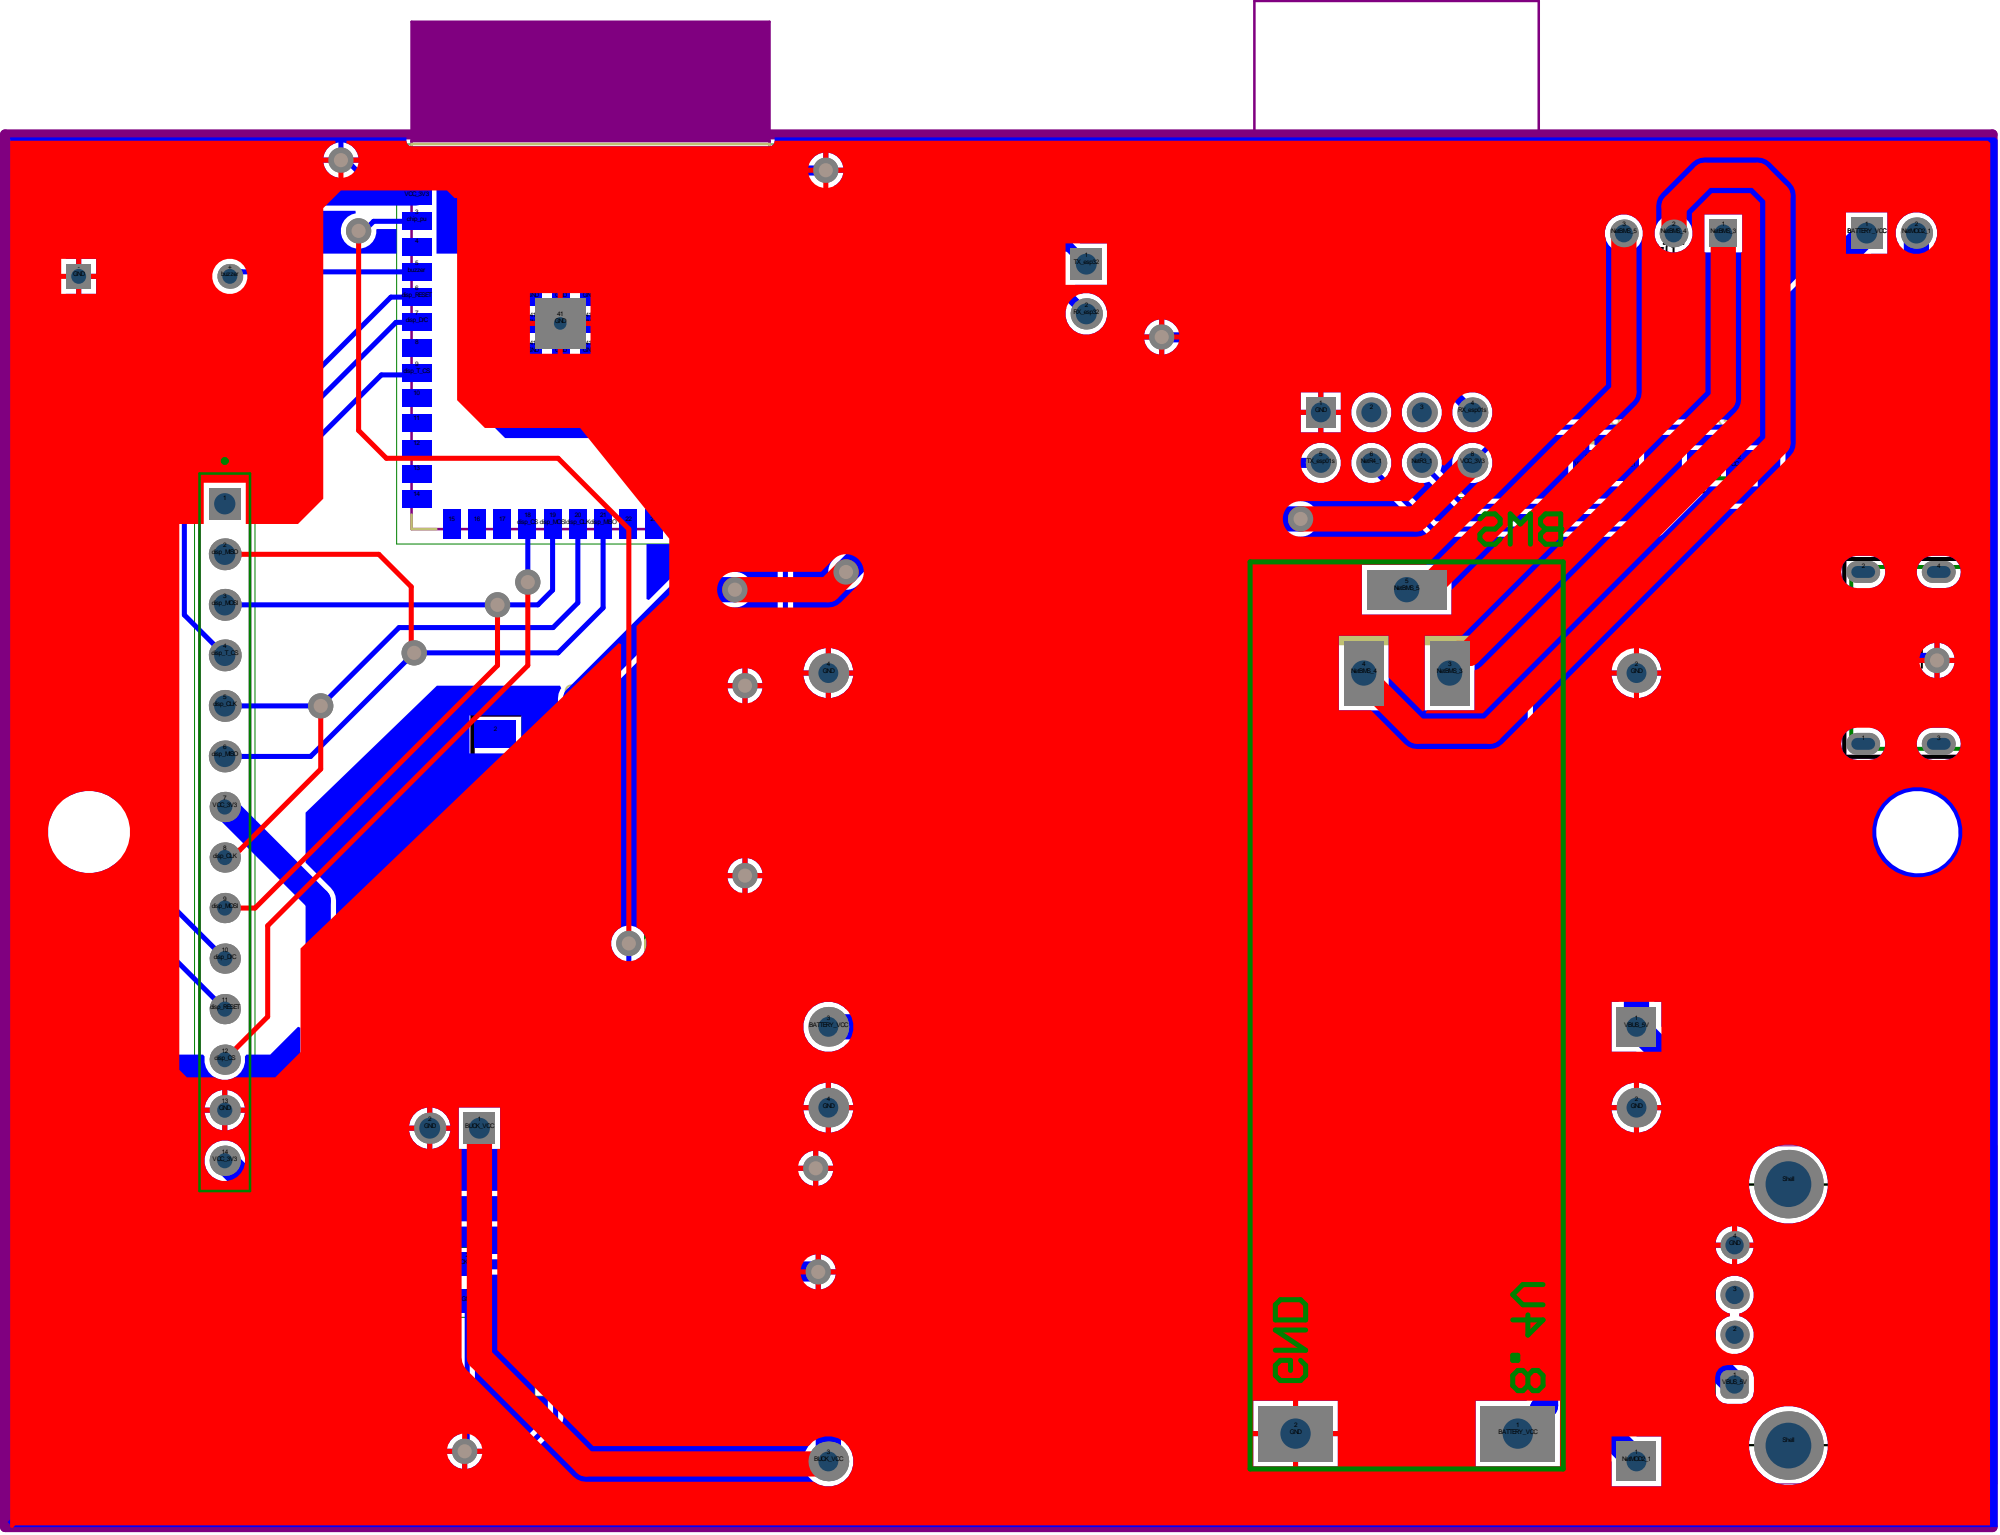
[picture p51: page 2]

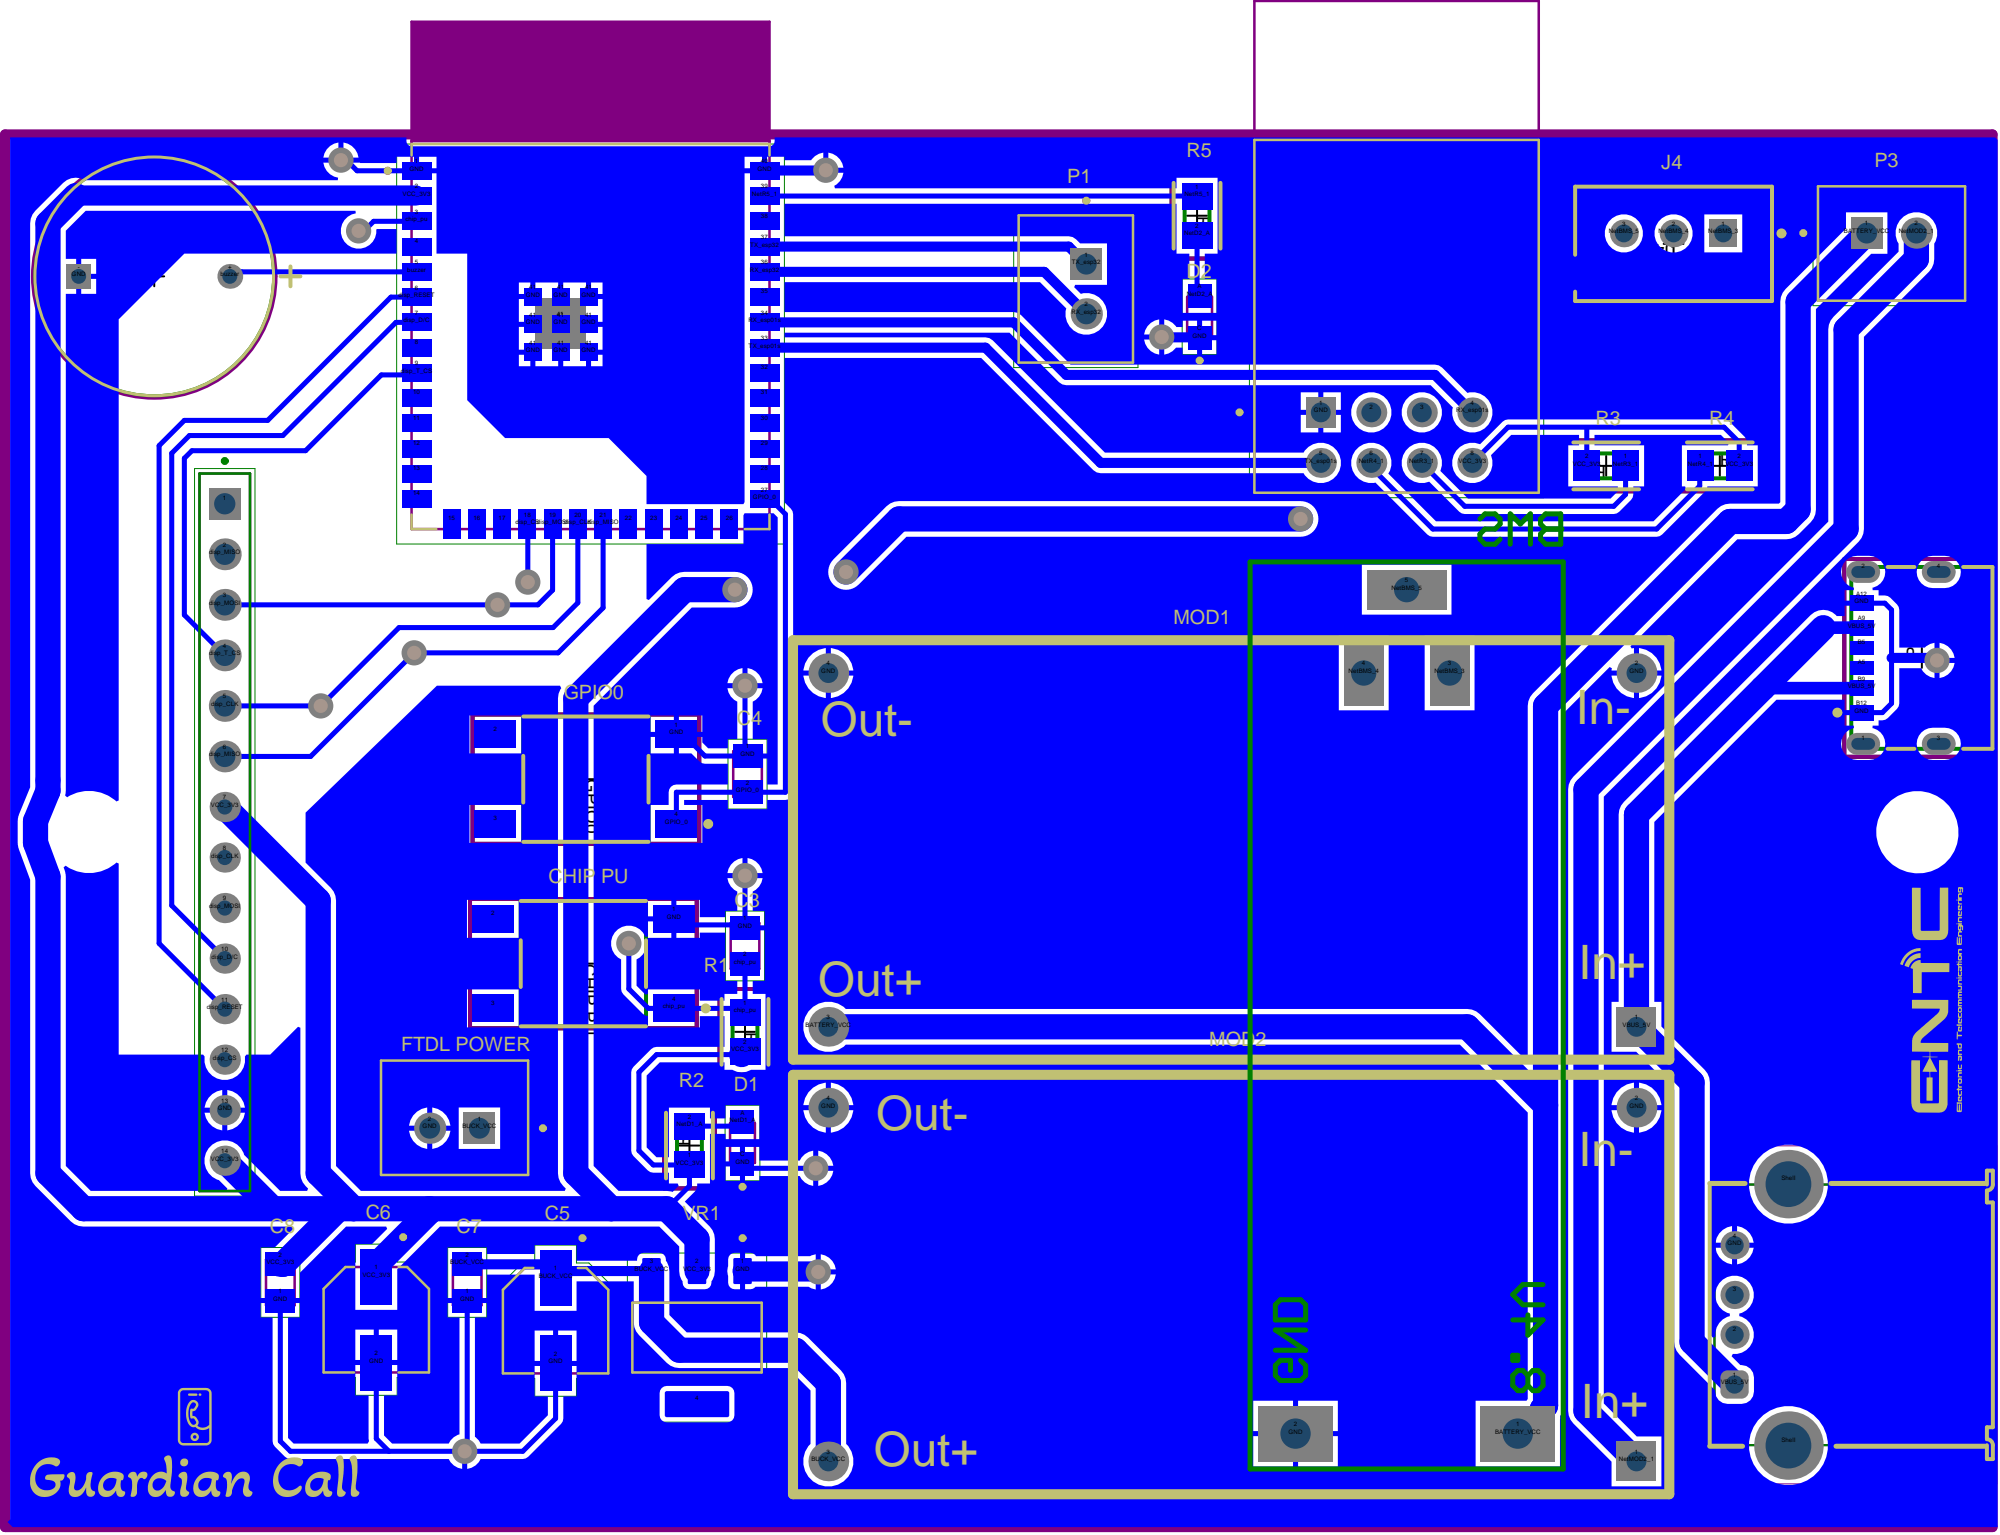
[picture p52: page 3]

TX_ esp | 0 1 | s

d isp _ T _ C | S | 3 2

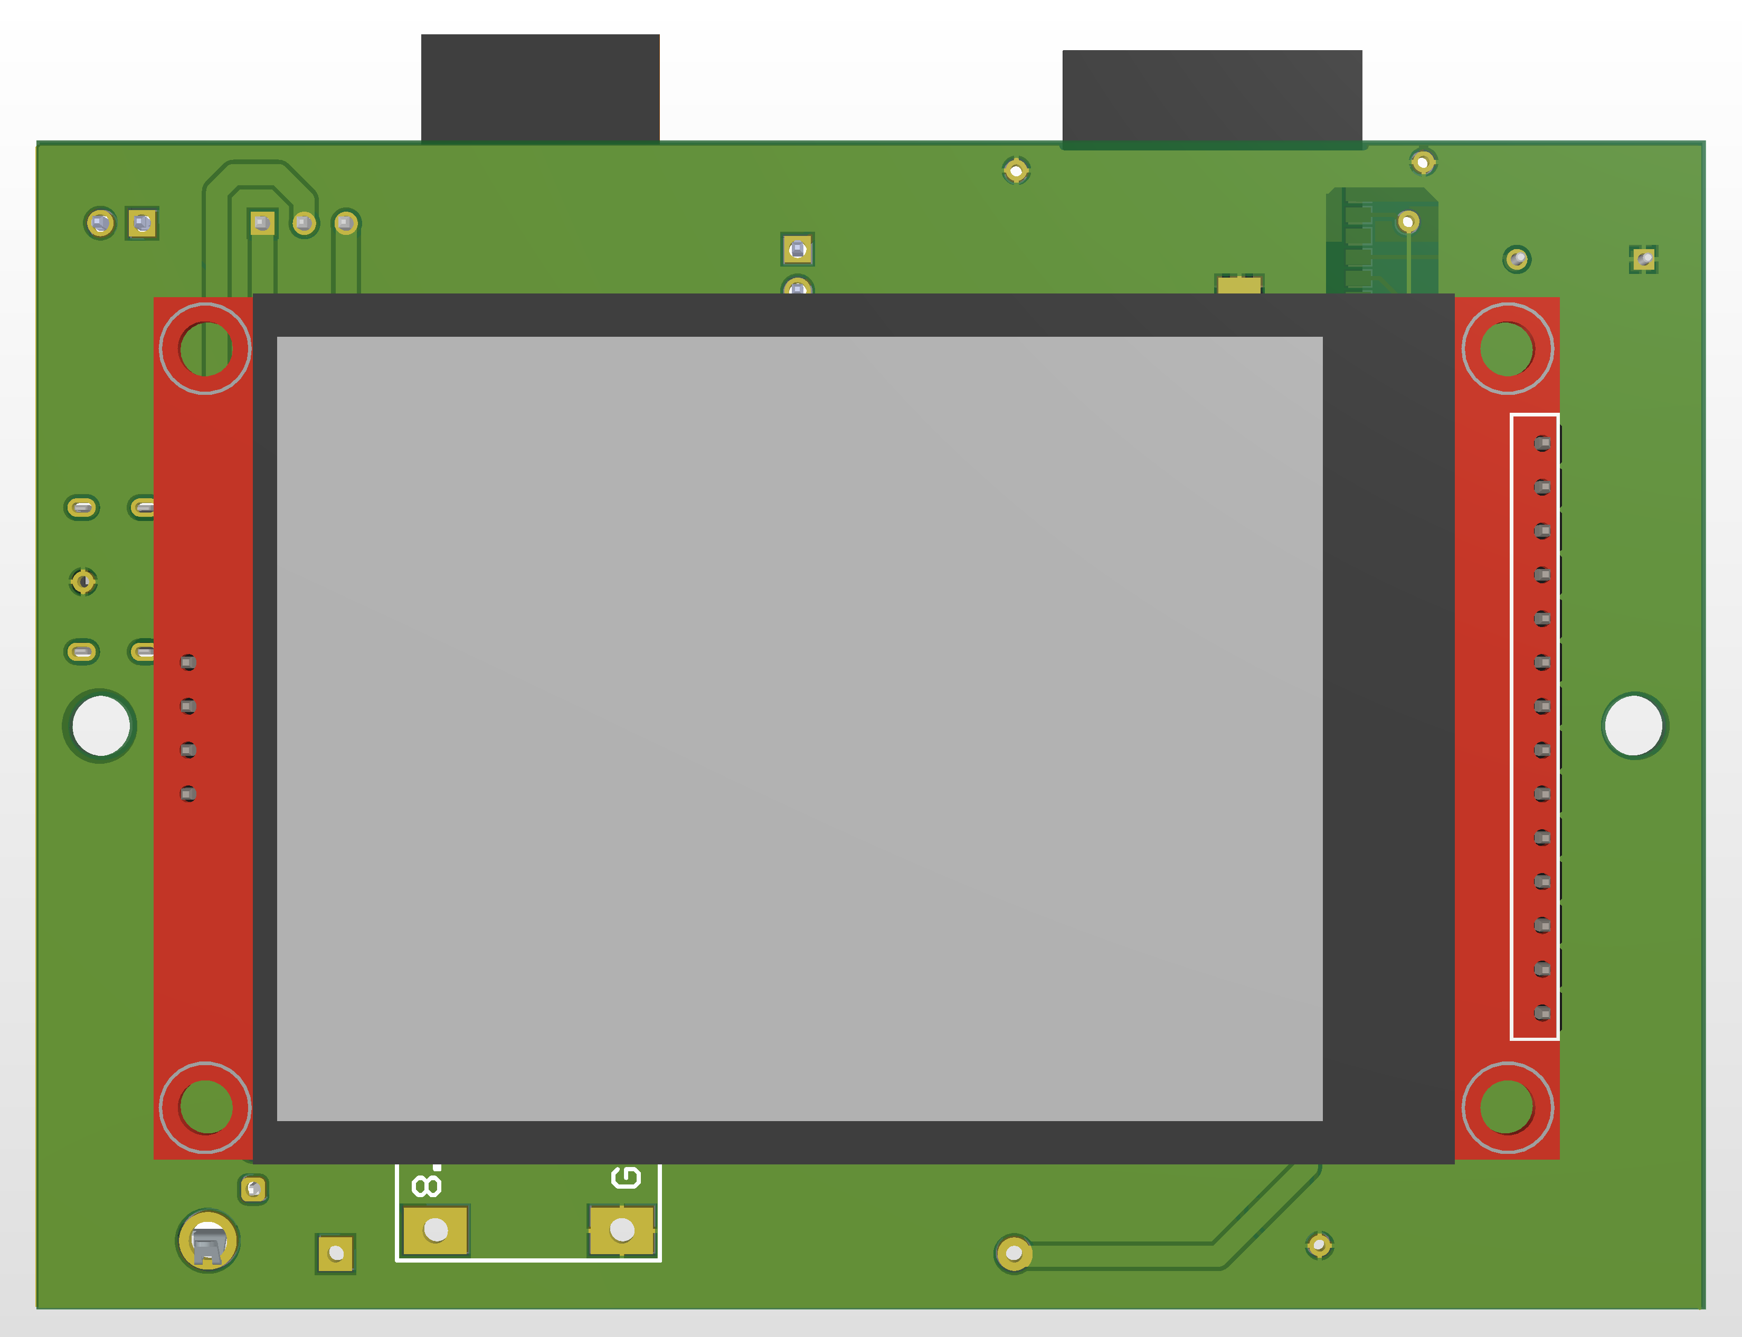
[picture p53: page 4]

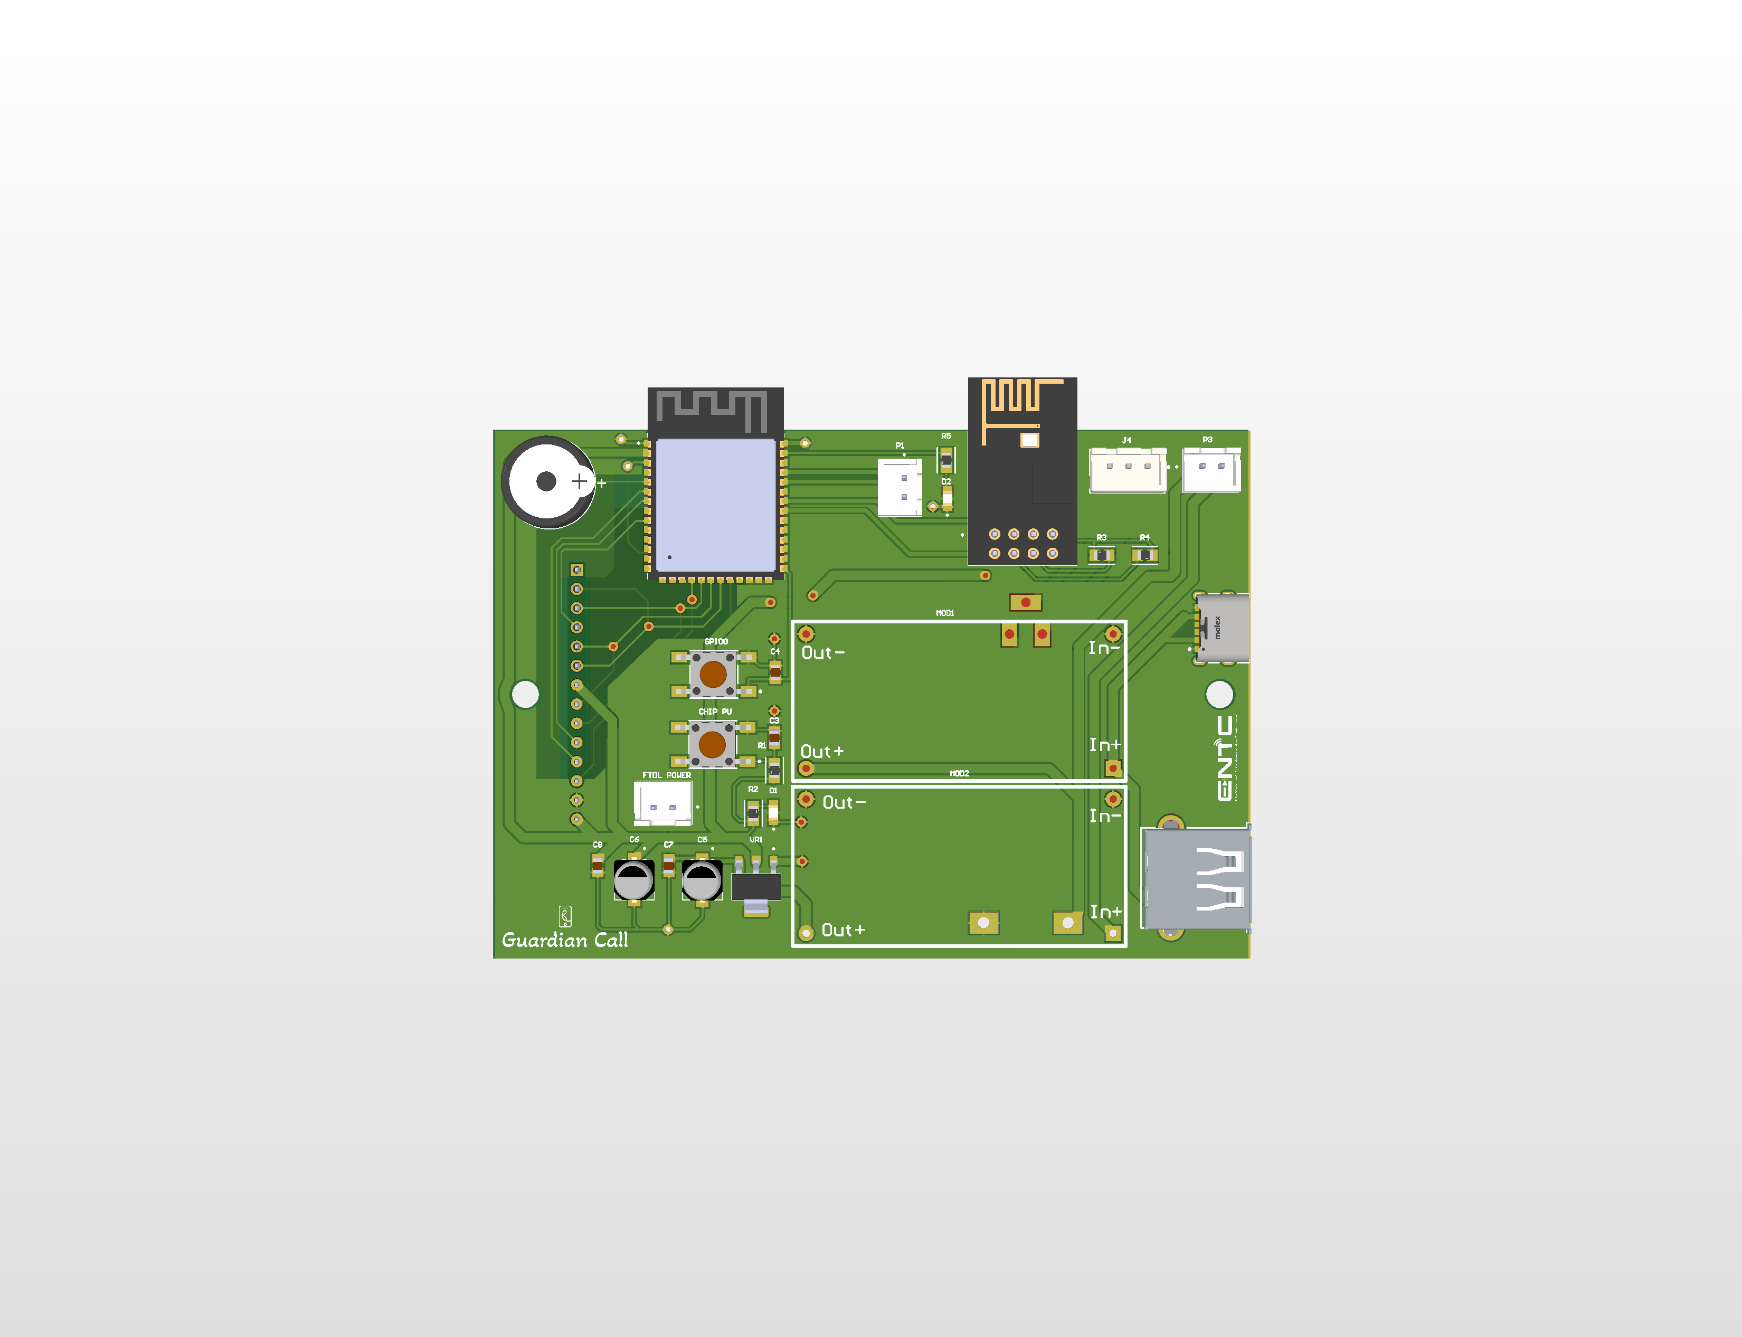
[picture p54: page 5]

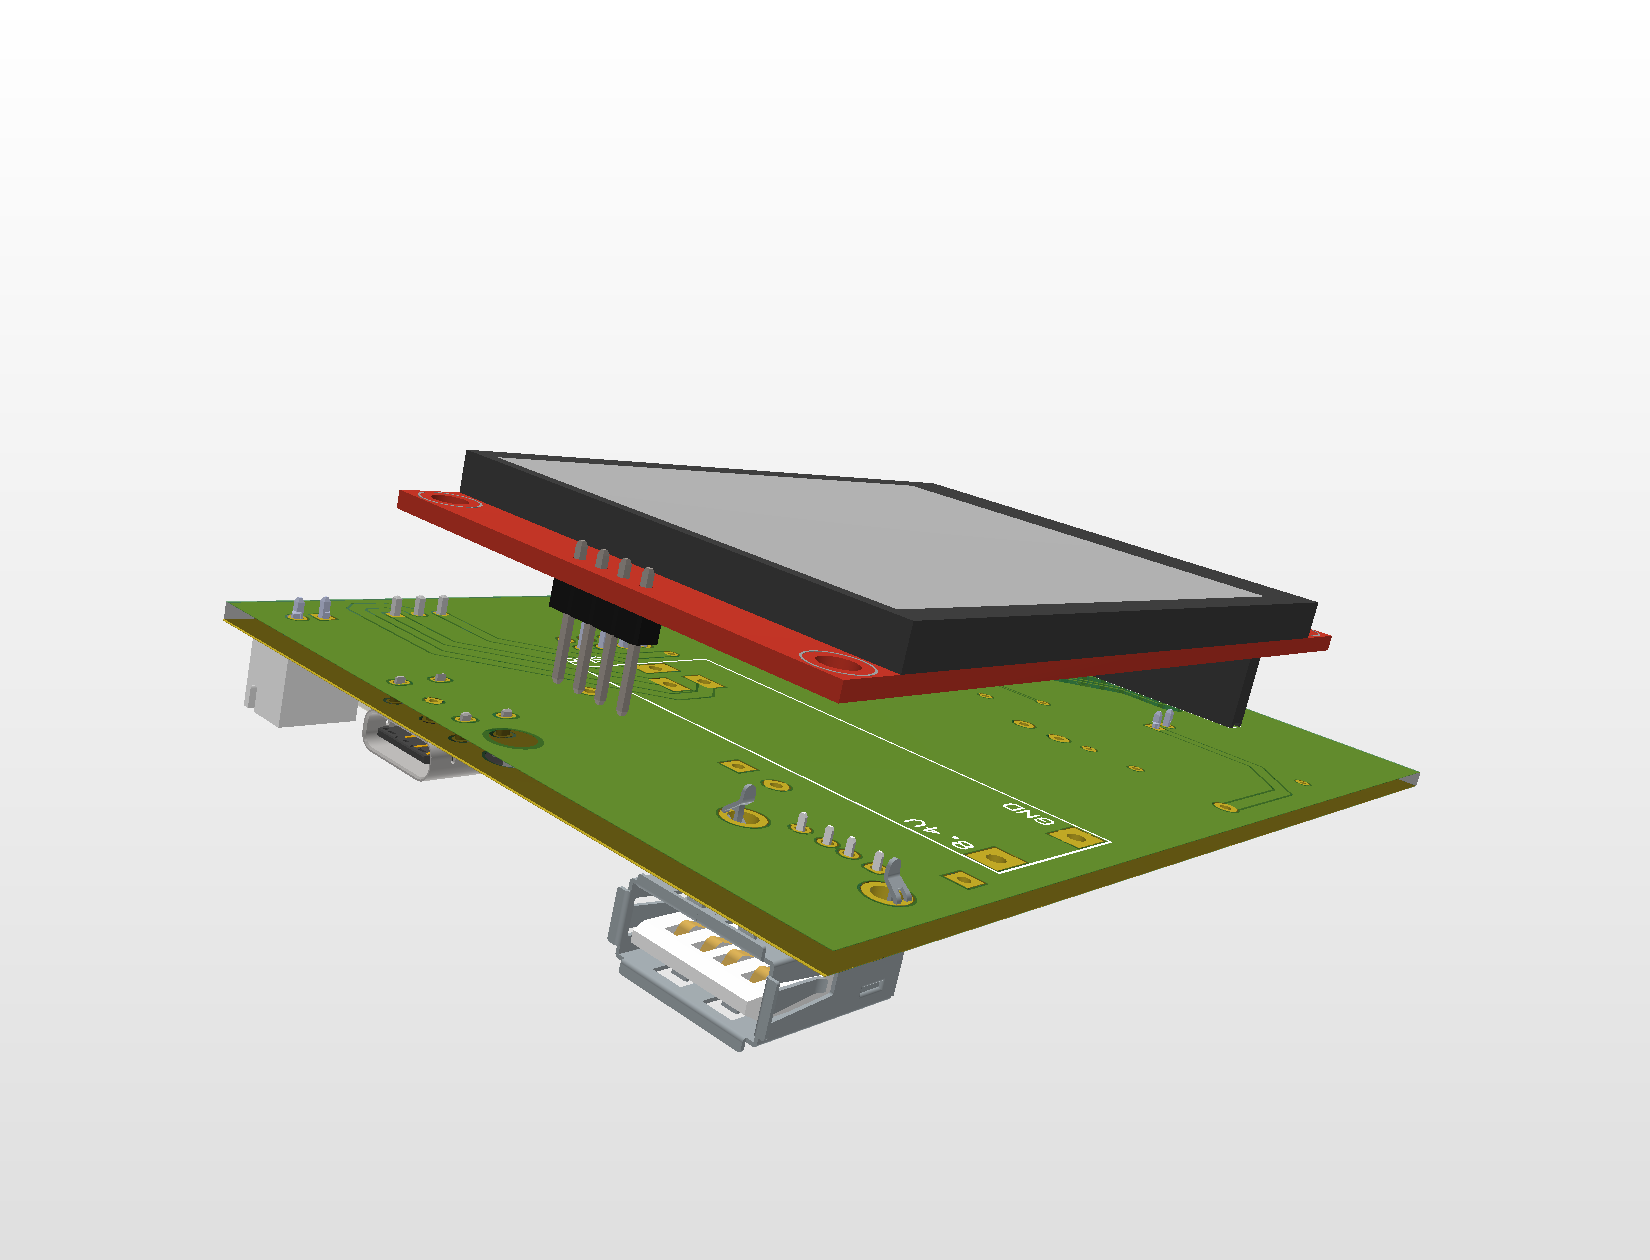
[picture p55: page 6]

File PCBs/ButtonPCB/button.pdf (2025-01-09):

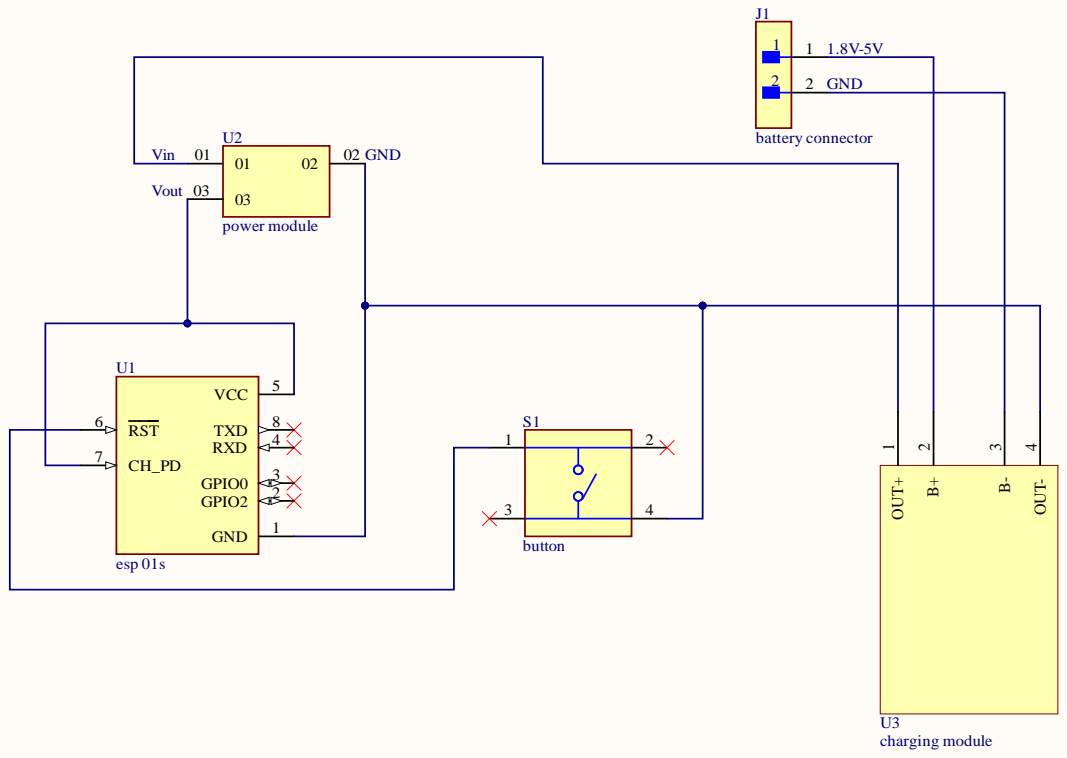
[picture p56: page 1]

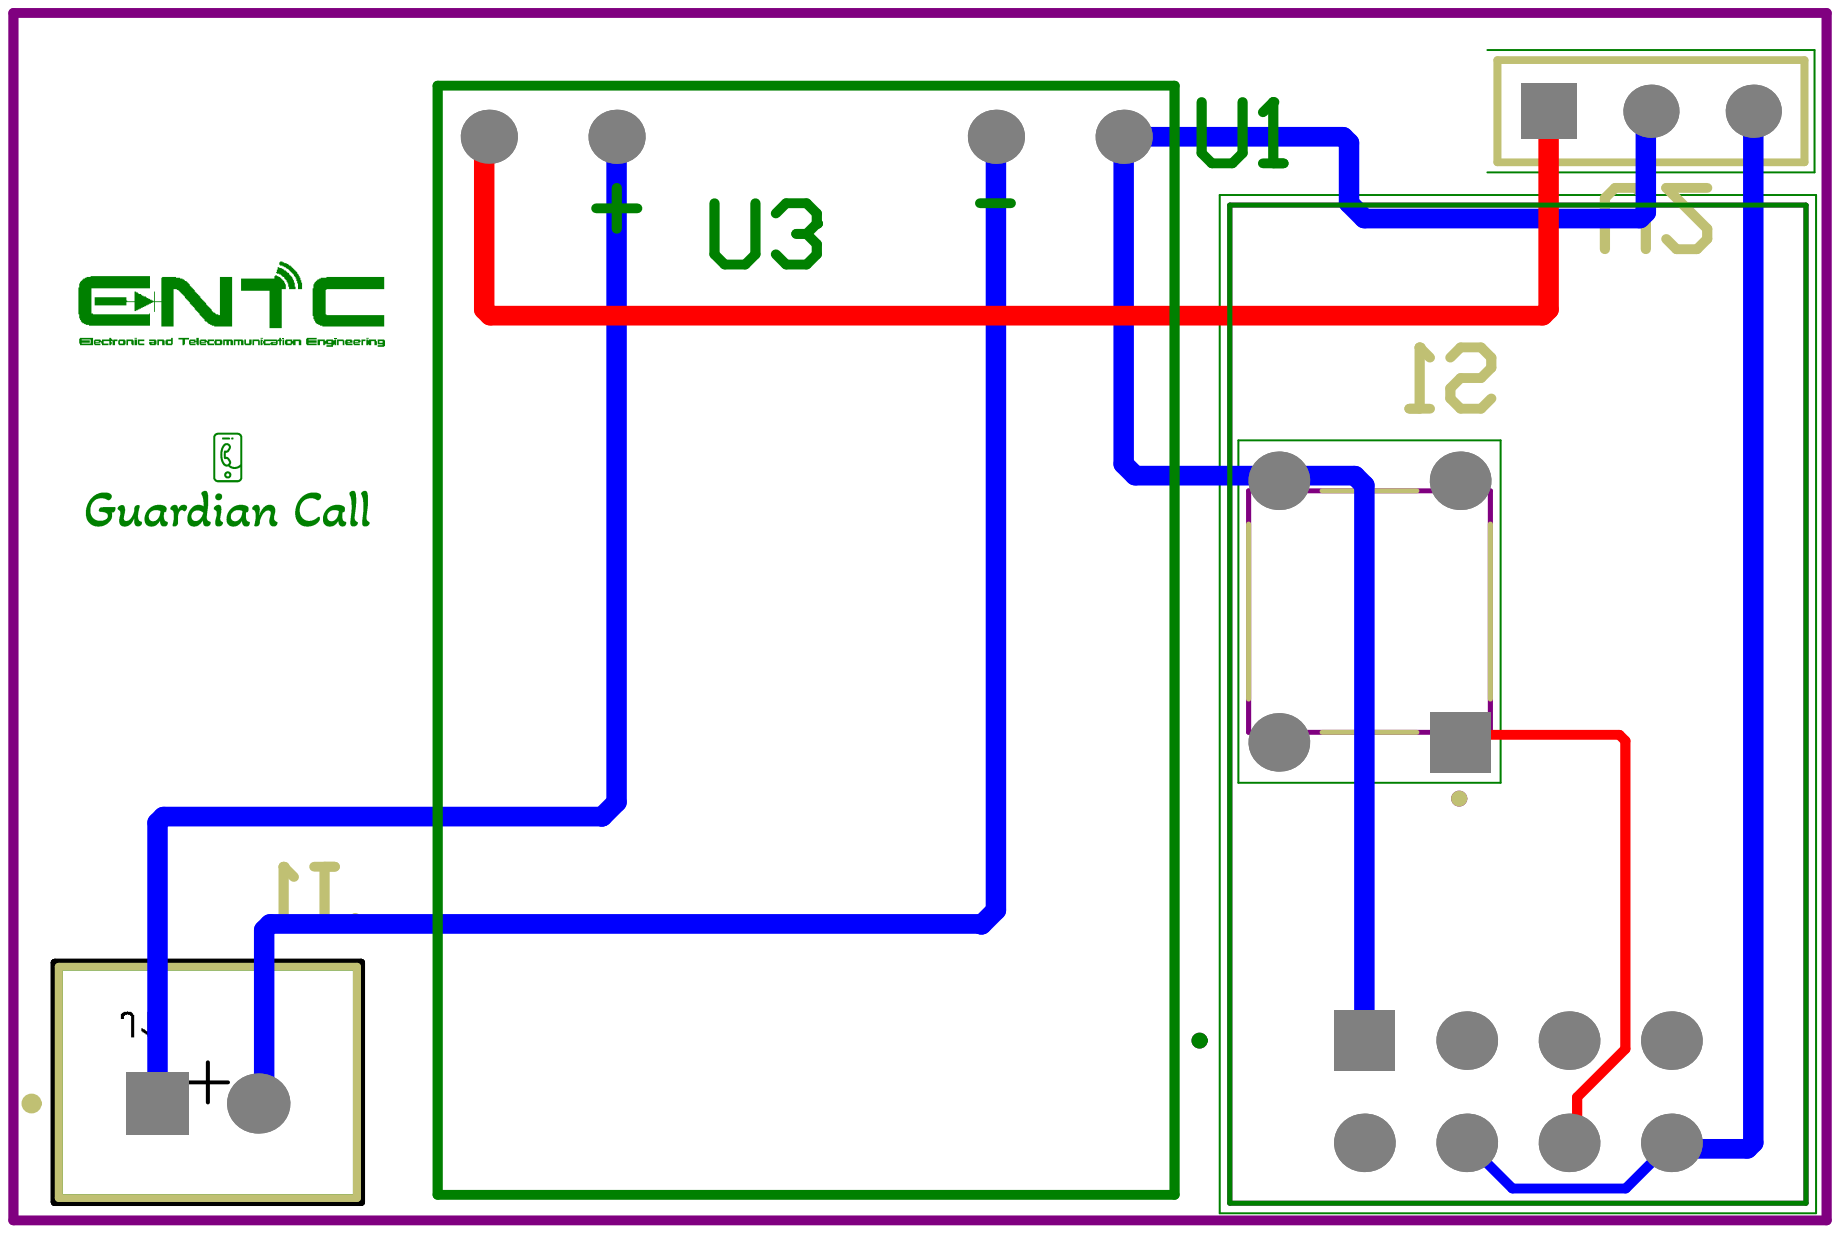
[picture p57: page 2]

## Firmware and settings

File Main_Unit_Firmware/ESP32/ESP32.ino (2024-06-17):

#include <WiFi.h>
#include "time.h"
#include <Preferences.h>
#include <TFT_eSPI.h>
#include <FS.h>

#include <Firebase_ESP_Client.h>
#include "addons/TokenHelper.h"
#include "addons/RTDBHelper.h"

#define TX_PIN 41
#define RX_PIN 40

#define API_KEY ""
#define DATABASE_URL ""

String deviceID = "100001";
String path;

TFT_eSPI tft = TFT_eSPI();
TFT_eSprite pwdField = TFT_eSprite(&tft);

unsigned long milliStart = 0;

String symbol[8][12] = {
  { "1", "2", "3", "4", "5", "6", "7", "8", "9", "0", "-", "=" },
  { "q", "w", "e", "r", "t", "y", "u", "i", "o", "p", "[", "]" },
  { "a", "s", "d", "f", "g", "h", "j", "k", "l", ";", "'", "\\" },
  { "z", "x", "c", "v", "b", "n", "m", ",", ".", "/", "`", " " },

  { "!", "@", "#", "$", "%", "^", "&", "*", "(", ")", "_", "+" },
  { "Q", "W", "E", "R", "T", "Y", "U", "I", "O", "P", "{", "}" },
  { "A", "S", "D", "F", "G", "H", "J", "K", "L", ":", "\"", "|" },
  { "Z", "X", "C", "V", "B", "N", "M", "<", ">", "?", "~", " " }
};


uint16_t calData[5] = { 396, 3350, 270, 3369, 7 };

const int buzzerPin = 5;
int pressTone = 2000;

unsigned long startTime = 0;
unsigned long elapsedTime = 0;

FirebaseData fbdo;
FirebaseAuth auth;
FirebaseConfig config;
bool signupOK = false;


const char* ssidMem = "ssid";
const char* passwordMem = "password";  // this "ssid" , "password" are not just the values, they defined how these variables should have  stored in the preferences library
//Neme9s8i7s
const char* isConnected = "isConnected";

Preferences preferences;

const char* ntpServer = "in.pool.ntp.org";
const long gmtOffset_sec = 19800;  //GMT+5:30
const int daylightOffset_sec = 0;

int prevIntTime;
String msg;
bool buzzerOn;
byte buzzerCount;

int hh ,mm, day , month , monthDay;

uint32_t btnID;
float battery;

void setup() {
  // Initialize Serial Monitor
  Serial.begin(115200);
  //Initializing serial communication betweeen master ESP01s
  Serial2.begin(115200, SERIAL_8N1, RX_PIN, TX_PIN);

  pinMode(buzzerPin, OUTPUT);

  //initializing tft object and initial display
  tft.init();
  tft.setRotation(1);
  tft.setTouch(calData);
  tft.fillScreen(TFT_BLACK);
  tft.setTextDatum(MC_DATUM);
  tft.setTextSize(2);

  //opens a preferences library with the namespace "WiFiVars" search for stored ssid and pwd in the preferences and return "" found none
  preferences.begin("WiFiVars");
  String ssid = preferences.getString(ssidMem, "");
  String password = preferences.getString(passwordMem, "");
  String isCon = preferences.getString(isConnected, "0");  //this memorize whether the device was connected to a wifi before the last turn off

  welcomeScreen();

  if (isCon == "0") {
    initialConnection();
  } else {
    if (!connectWifi(ssid, password)) {
      ESP.restart();
    };
  }
  // Init and get the time
  configTime(gmtOffset_sec, daylightOffset_sec, ntpServer);

  config.api_key = API_KEY;
  config.database_url = DATABASE_URL;

  Serial.print("Sign up new user... ");
  if (Firebase.signUp(&config, &auth, "", "")) {
    Serial.println("ok");
    signupOK = true;
  } else {
    Serial.printf("%s\n", config.signer.signupError.message.c_str());
  }

  // Assign the callback function for the long running token generation task.
  config.token_status_callback = tokenStatusCallback;  //--> see addons/TokenHelper.h

  Firebase.begin(&config, &auth);
  Firebase.reconnectWiFi(true);

  //interupt is caused by esp01s
  //attachInterrupt(digitalPinToInterrupt(triggerPin), serialInteruptHandler, RISING);
}

void loop() {

  esp01toEsp32();

  struct tm time = getLocalTime();

  hh = (int)time.tm_hour;
  mm = (int)time.tm_min;
  day = (int)time.tm_wday;
  month = (int)time.tm_mon;
  monthDay = (int)time.tm_mday;


  int intTime = hh * 100 + mm;

  if (WiFi.status() != 3) {
    Serial.println("WiFi Connection lost");

    byte input = wifiConnectionLost();  // Read touch input... 1 - new wifi, 2 wait
    if (input == 1) {
      String isCon = "0";
      preferences.putString(isConnected, isCon.c_str());
      ESP.restart();

    } else {
      tft.fillScreen(TFT_BLACK);
      tft.setTextColor(TFT_WHITE);
      tft.drawString("Restart if you want to", 160, 120, 1);
      tft.drawString("change networks", 160, 140, 1);
      delay(3000);
      while (WiFi.status() != 3) {
        clockNoAlarm(hh, mm, day, month, monthDay);
        tft.setTextColor(TFT_WHITE);
        tft.drawString("No Connection", 160, 200, 1);
      }
    }
  }

  if (prevIntTime != intTime) {
    prevIntTime = intTime;
    Serial.println(&time, "%A, %B %d %H:%M");

    path = "Devices/" + deviceID + "/Alarms/" + day + "/" + intTime;
    if (Firebase.ready() && signupOK) {
      if (Firebase.RTDB.getString(&fbdo, path)) {
        msg = fbdo.stringData();
        Serial.println(msg);
        buzzerOn = true;
        buzzerCount = 0;
        alarmDisplay(hh, mm, msg);
      } else {
        if ((String)fbdo.errorReason() == "path not exist") {
          Serial.print("No alarms at : ");
          Serial.println(&time, "%H:%M");
          buzzerOn = false;
          clockNoAlarm(hh, mm, day, month, monthDay);
        }
      }
    }
  }

  if (prevIntTime == intTime && buzzerOn && buzzerCount < 20) {
    tone(buzzerPin, 1000);
    delay(400);
    tone(buzzerPin, 3000);
    delay(400);
    noTone(buzzerPin);
    delay(400);
    buzzerCount++;
  }
}


//Callback used when it is need to send button press event to the firebase
void esp01toEsp32() {
  //put a tone here
  if (Serial2.available() ) {
    btnID = Serial2.readStringUntil('\n').toInt();
    Serial.println(btnID);
    battery = Serial2.readStringUntil('\n').toFloat();
    Serial.println(battery);

    while (Serial2.available() ) {
      if (Serial2.readStringUntil('\n').toInt() == btnID){
        Serial2.read();  // Read and discard each byte in the buffer so even though the button send it couple of times by one press it won't affect
      }else{
        break;
      }
    }

    String btnPathStatus = "Devices/" + deviceID + "/Buttons/" + btnID + "/Status/";
    String btnPathBat = "Devices/" + deviceID + "/Buttons/" + btnID + "/Battery/";


    if (Firebase.ready() && signupOK && btnID != 0) {
      // Write an btn status and battery percentage on the database path specified for the button ID.
      if (Firebase.RTDB.setInt(&fbdo, btnPathStatus, 1)) {
        Firebase.RTDB.setFloat(&fbdo, btnPathBat, battery);
        Serial.println("PASSED");
        tone(buzzerPin, 3000);
        delay(2000);
        noTone(buzzerPin);
      } else {
        Serial.println("Failed: " + fbdo.errorReason());
      }
    } else if (btnID != 0) {
      Serial.print("Firebase Sign up error... SignUp status : ");
      Serial.println(signupOK);
    }
  }
}


struct tm getLocalTime() {
  struct tm timeinfo;

  if (!getLocalTime(&timeinfo)) {
    Serial.println("Failed to obtain time");
    return {};
  }
  return timeinfo;
}


void initialConnection() {

  //remove when touch available
  tft.fillScreen(TFT_BLACK);
  tft.setTextColor(TFT_WHITE);
  tft.setTextDatum(BL_DATUM);
  tft.drawString("Select a Network", 15, 20, 1);

  byte numNetworks = WiFi.scanNetworks();  //scan for wifi networks and return number of networks found

  //display this after sorting according to RSSI
  String temp;
  for (int i = 0; i < numNetworks; ++i) {
    temp = String(i + 1) + ") " + String(WiFi.SSID(i));
    tft.drawString(temp, 5, 40 + i * 20, 1);
    tft.drawRoundRect(2, 22 + i * 20, 318, 18, 5, TFT_CYAN);
    //Iterate over WiFi object (global arduino core object) i times
  }

  uint16_t x = 0, y = 0;  // To store the touch coordinates

  int pressedIndex = 0;
  while (pressedIndex == 0) {
    bool pressed = tft.getTouch(&x, &y);
    if (pressed) {
      for (int i = 1; i <= 11; i++) {
        if (y > i * 20 && y < (i + 1) * 20) {
          pressedIndex = i;
          tone(buzzerPin, pressTone);
          delay(100);
          noTone(buzzerPin);
          break;
        }
      }
    }
  }

  String inpSSID = WiFi.SSID(pressedIndex - 1);


  String inpPassword = getKeyboardOut(inpSSID);

  bool connectWifiResponse = connectWifi(inpSSID, inpPassword);

  if (connectWifiResponse) {
    preferences.putString(isConnected, "1");
  }
}


bool connectWifi(String id, String pwd) {
  // Connect to Wi-Fi
  tft.fillScreen(TFT_BLACK);
  tft.setTextColor(TFT_WHITE);
  tft.setTextDatum(MC_DATUM);
  tft.drawString("Connecting to" , 160 , 100 ,1);
  tft.drawString(id, 160, 135, 1);
  WiFi.begin(id.c_str(), pwd.c_str(), 1);

  byte attempts = 0;
  while (WiFi.status() != WL_CONNECTED) {
    delay(500);
    attempts++;
    Serial.print(".");
    //Serial.println(WiFi.status());
    if (attempts > 20) {
      tft.fillScreen(TFT_BLACK);
      tft.setTextColor(TFT_RED);
      tft.drawString("Can't connect to", 160, 100, 1);
      tft.drawString(id, 160 ,135 , 1);
      tft.drawString("Check your credentials", 160, 170, 1);
      preferences.putString(isConnected, "0");
      delay(2000);
      WiFi.disconnect(true);
      ESP.restart();
      return false;
    }
  }

  if (WiFi.status() == WL_CONNECTED) {
    tft.fillScreen(TFT_BLACK);
    tft.setTextColor(TFT_GREEN);
    tft.drawString("WiFi Connected...", 160, 120, 2);
    preferences.putString(ssidMem, id.c_str());  //stores the successfully conneted wifi credentials on the preferences namespace named WiFiVars
    preferences.putString(passwordMem, pwd.c_str());
    return true;
  }
}

void welcomeScreen() {
  //Welcome Screen
  tft.setTextDatum(MC_DATUM);
  tft.setTextSize(2);
  tft.drawString("Guardian", 160, 60, 4);
  tft.drawString("Call", 160, 180, 4);
  delay(500);
  tft.drawString("<           >", 160, 120, 4);
  delay(500);
  tft.drawString(".", 120, 120, 4);
  delay(500);
  tft.drawString(".", 140, 120, 4);
  delay(500);
  tft.drawString(".", 160, 120, 4);
  delay(500);
  tft.drawString(".", 180, 120, 4);
  delay(500);
  tft.drawString(".", 200, 120, 4);
  delay(1000);
}


String clockNoAlarm(int hh, int mm, int day, int month, int monthDay) {
  tft.fillScreen(TFT_BLACK);
  tft.setTextColor(TFT_RED);
  tft.setTextDatum(MC_DATUM);
  String nowTime = analogTime(hh, mm);

  tft.drawString(nowTime, 160, 120, 7);

  String dayName;
  String monthName;
  String dayString;

  switch (day) {
    case 0:
      dayName = "Sunday";
      break;
    case 1:
      dayName = "Monday";
      break;
    case 2:
      dayName = "Tuesday";
      break;
    case 3:
      dayName = "Wednesday";
      break;
    case 4:
      dayName = "Thursday";
      break;
    case 5:
      dayName = "Friday";
      break;
    case 6:
      dayName = "Saturday";
      break;
  }

  switch (month) {
    case 0:
      monthName = "January";
      break;
    case 1:
      monthName = "February";
      break;
    case 2:
      monthName = "March";
      break;
    case 3:
      monthName = "April";
      break;
    case 4:
      monthName = "May";
      break;
    case 5:
      monthName = "June";
      break;
    case 6:
      monthName = "July";
      break;
    case 7:
      monthName = "August";
      break;
    case 8:
      monthName = "September";
      break;
    case 9:
      monthName = "October";
      break;
    case 10:
      monthName = "November";
      break;
    case 11:
      monthName = "December";
      break;
  }

  dayString = dayName + " , " + monthName + " " + String(monthDay);
  tft.drawString(dayString, 160, 40, 2);

  return nowTime;
}

void alarmDisplay(int hh, int mm, String msg) {
  tft.fillScreen(TFT_BLACK);
  tft.setTextColor(TFT_RED);
  tft.setTextDatum(MC_DATUM);

  String nowTime = analogTime(hh, mm);
  nowTime = "Alarm at " + nowTime;
  tft.drawString(nowTime, 160, 20, 2);

  int x = 7, y = 55;
  int length;
  String word = "";
  tft.setTextDatum(ML_DATUM);
  tft.setTextColor(TFT_WHITE);
  for (int i = 0; i < msg.length(); i++) {
    char currentChar = msg.charAt(i);
    word += currentChar;
    if (currentChar == ' ') {
      length = (int)word.length();
      if (x + 14 * (length - 1) > 320) {
        x = 7;
        y += 26;
      }
      tft.drawString(word, x, y, 2);
      x += 14 * (length);
      word = "";
    }
  }
  length = (int)word.length();
  if (x + 14 * (length - 1) > 320) {
    x = 7;
    y += 26;
  }
  tft.drawString(word, x, y, 2);
  x += 14 * (length);
  word = "";
}

String analogTime(int hh, int mm) {
  if (hh > 12) {
    hh = hh - 12;
  }

  String strhh;
  if (hh < 10) {
    strhh = "0" + String(hh);
  } else {
    strhh = String(hh);
  }
  String strmm;
  if (mm < 10) {
    strmm = "0" + String(mm);
  } else {
    strmm = String(mm);
  }
  String nowTime = strhh + ":" + strmm;
  return nowTime;
}

//ButtonConnectDisplay and ButtonConnectResponse removed... See Old code

int wifiConnectionLost() {
  // add a 20s sprite countdown

  tft.fillScreen(TFT_BLACK);
  tft.setTextDatum(MC_DATUM);
  tft.setTextColor(TFT_WHITE);
  tft.drawString("WiFi disconnected...", 160, 80, 2);
  tft.fillRoundRect(55, 110, 200, 40, 10, 0x4B60);  //green
  tft.fillRoundRect(55, 170, 200, 40, 10, TFT_BLUE);
  tft.drawString("Connect New WiFi", 160, 130, 1);
  tft.drawString("Wait", 160, 190, 1);

  uint16_t x = 0, y = 0;  // To store the touch coordinates

  bool changePressed = false;
  bool waitPressed = false;
  startTime = millis();
  while (!(changePressed || waitPressed) && (millis() - startTime) < 20000) {
    bool pressed = tft.getTouch(&x, &y);

    tone(buzzerPin, 2500);
    delay(100);
    noTone(buzzerPin);

    if (pressed) {
      if (x > 55 && x < 255 && y > 110 && y < 150) {
        changePressed = true;
        tone(buzzerPin, pressTone);
        delay(100);
        noTone(buzzerPin);
        Serial.println("Connecting New");
        return 1;
      }
      if (x > 55 && x < 255 && y > 170 && y < 210) {
        waitPressed = true;
        tone(buzzerPin, pressTone);
        delay(100);
        noTone(buzzerPin);
        Serial.println("Waiting");
        return 2;
      }
    }
    delay(100);
  }
  return 2;
}


String getKeyboardOut(String ssid) {
  uint16_t x = 0, y = 0;
  String pwd = "";
  String pressedKey;

  byte xIndex, yIndex;
  bool enterPressed = false;
  bool capsOn = false;

  pwdField.createSprite(315, 40);

  drawButtons(capsOn, ssid);

  milliStart = millis();

  while (!enterPressed) {
    bool pressed = tft.getTouch(&x, &y);
    if (pressed && (millis() - milliStart) > 400) {
      if (y > 85) {
        tone(buzzerPin, pressTone);
        delay(100);
        noTone(buzzerPin);
      }

      if (x < 55 && y > 201) {
        if (capsOn) {
          capsOn = false;
        } else {
          capsOn = true;
        }
        drawButtons(capsOn, ssid);
      }

      if (x > 55 && x < 193 && y > 201) {
        pressedKey = " ";
      }

      if (x > 193 && x < 249 && y > 201) {
        if (pwd != "") {
          pwd.remove(pwd.length() - 1);
          pwdField.fillSprite(TFT_WHITE);
        }
      }

      if ((x > 249 && y > 201) || (x > 287 && y > 172)) {
        if (enterPressed) {
          enterPressed = false;
        } else {
          enterPressed = true;
        }
      }

      if (y > 85 && y < 201) {
        if (capsOn) {
          xIndex = (int)(x - 1) / 26;
          yIndex = (int)(((y - 85)) / 29 + 4);
        } else {
          xIndex = (int)(x - 1) / 26;
          yIndex = (int)(((y - 85)) / 29);
        }
        pressedKey = String(symbol[yIndex][xIndex]);
      }

      milliStart = millis();

      pwd += pressedKey;

      Serial.println(pressedKey);
      Serial.println(pwd);

      pwdField.drawString(pwd, 10, 35, 4);
      pwdField.pushSprite(0, 40);

      pressedKey = "";
    }
  }

  return pwd;
}

void drawButtons(bool isCapsOn, String inpSSID) {
  tft.fillScreen(TFT_BLACK);
  String temp = "Enter password " + inpSSID;
  tft.fillScreen(TFT_BLACK);
  tft.setTextColor(TFT_WHITE);
  tft.setTextDatum(BL_DATUM);
  tft.drawString(temp, 5, 20, 1);

  pwdField.fillSprite(TFT_WHITE);
  pwdField.setRotation(1);
  pwdField.setTextDatum(BL_DATUM);
  pwdField.setTextColor(TFT_BLACK, TFT_WHITE);
  pwdField.pushSprite(0, 40);

  tft.setTextSize(2);
  tft.setTextColor(TFT_RED);
  if (!isCapsOn) {
    for (int j = 0; j < 4; j++) {
      for (int i = 0; i < 12; i++) {
        tft.fillRoundRect((i * 26) + 1, j * 29 + 85, 25, 28, 3, TFT_YELLOW);
        tft.setCursor(i * 26 + 6, j * 29 + 90);
        tft.print(symbol[j][i]);
      }
    }
  } else {
    for (int j = 4; j < 8; j++) {
      for (int i = 0; i < 12; i++) {
        tft.fillRoundRect((i * 26) + 1, (j - 4) * 29 + 85, 25, 28, 3, TFT_YELLOW);
        tft.setCursor(i * 26 + 6, (j - 4) * 29 + 90);
        tft.print(symbol[j][i]);
      }
    }
  }
  tft.fillRoundRect(1, 201, 55, 28, 3, TFT_CYAN);
  tft.setTextColor(TFT_BLACK);
  tft.setTextSize(2);
  tft.setCursor(5, 211);
  tft.print("Caps");

  tft.fillRoundRect(57, 201, 135, 28, 3, TFT_CYAN);
  tft.setTextColor(TFT_BLACK);
  tft.setTextSize(2);
  tft.setCursor(100, 211);
  tft.print("Space");

  tft.fillRoundRect(193, 201, 55, 28, 3, TFT_CYAN);
  tft.setTextColor(TFT_BLACK);
  tft.setTextSize(2);
  tft.setCursor(198, 211);
  tft.print("Back");

  tft.fillRoundRect((11 * 26) + 1, (3) * 29 + 85, 25, 33, 3, TFT_CYAN);
  tft.fillRoundRect(249, 201, 63, 28, 3, TFT_CYAN);
  tft.setTextColor(TFT_BLACK);
  tft.setTextSize(2);
  tft.setCursor(253, 211);
  tft.print("Enter");
}

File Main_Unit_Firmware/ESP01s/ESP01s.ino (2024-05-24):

#include <espnow.h>
#include <ESP8266WiFi.h>

struct __attribute__((packed)) dataPacket {
  uint32_t buttonID;
  float battery;
} packet;


uint32_t btnID;
float batteryPer;

bool received = false;

void OnDataRecv(uint8_t* mac, uint8_t* incomingData, uint8_t len) {
  // callback function that will be executed when data is received
  dataPacket packet;
  memcpy(&packet, incomingData, sizeof(packet));
  btnID = packet.buttonID;
  batteryPer = packet.battery;

  received = true;
  Serial.println(btnID);
  Serial.println(batteryPer);
}

void setup() {
  Serial.begin(115200);

  WiFi.mode(WIFI_STA);

  //0 is used instead of ESP_OK as apparently it isn't defined in the header
  if (esp_now_init() != 0) {
    Serial.println("Error initializing ESP-NOW");
    return;
  }
  esp_now_set_self_role(ESP_NOW_ROLE_SLAVE);
  esp_now_register_recv_cb(OnDataRecv);
}

void loop(){
  if (received == true){
    Serial.println(btnID);
    Serial.println(batteryPer);
  }
  received = false;
}

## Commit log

2024-05-24 Changed the code base after deciding to employ seperate esp01s module for the main unit to communicate via esp-now protocol with the buttons. (Instead of buttons trying to connect to the wifi and fir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
2025-01-09 added all files except enclosure
    [PCB1.GBL, PCB1.GBO, PCB1.GBP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]
